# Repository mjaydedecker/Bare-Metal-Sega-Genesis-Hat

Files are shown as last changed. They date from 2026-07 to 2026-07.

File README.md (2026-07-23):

# Sega Genesis Controller HAT

A passive Raspberry Pi HAT exposing two DB9 (DE-9) ports for original Sega
Genesis / Mega Drive controllers, wired directly to the Pi's 40-pin GPIO
header.

<p align="center">
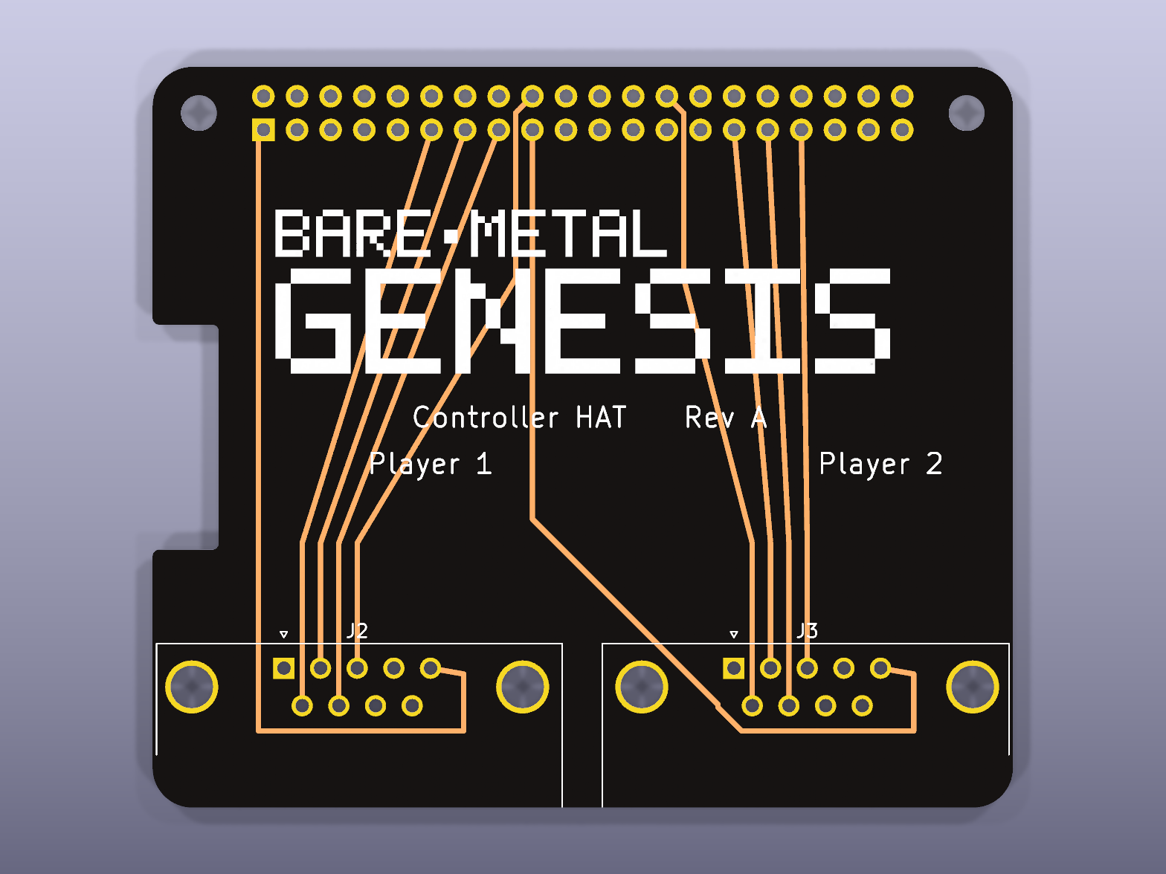
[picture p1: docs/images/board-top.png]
Board top render
  
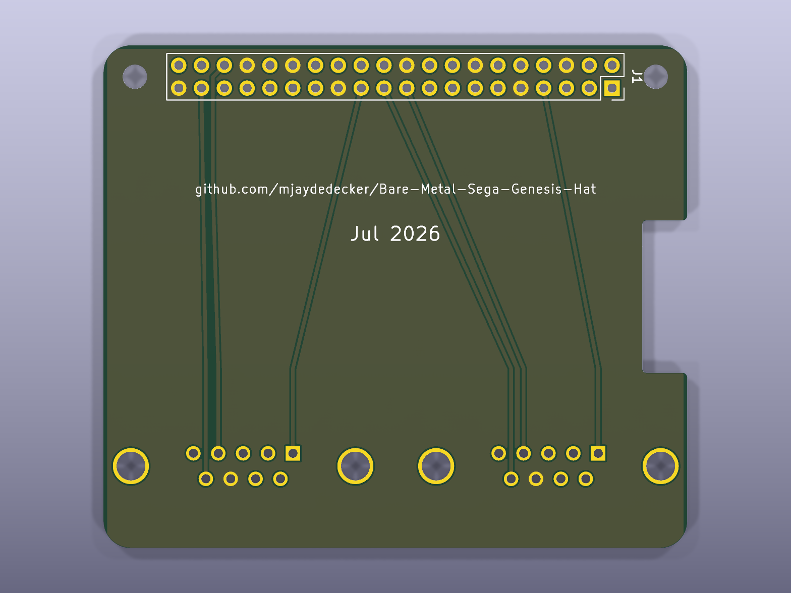
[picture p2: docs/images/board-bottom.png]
Board bottom render
  
</p>

Licensed under [CERN-OHL-S v2](LICENSE) — see [License](#license) below.

This board has no firmware of its own. The pin assignment and electrical
contract it implements are owned by the firmware repo,
[Bare-Metal-Sega-Genesis](../Bare-Metal-Sega-Genesis), specifically
`src/input/sega_board.h` and
`docs/superpowers/specs/2026-06-25-gpio-sega-controllers-design.md`. If
those ever disagree with this repo, the firmware repo wins — update this
board to match it, not the other way around.

See `docs/superpowers/specs/2026-07-21-controller-hat-v1-design.md` for the
full design rationale (why no ID EEPROM, no protection circuitry, no
stacking header) and `docs/superpowers/plans/2026-07-21-controller-hat-v1.md`
for how it was built.

A GitHub Actions workflow (`.github/workflows/verify-pinmap.yml`) checks on
every push that this board's schematic wiring matches the firmware repo's
`sega_board.h` exactly.

## Files

- `genesis-controller-hat.kicad_pro` / `.kicad_sch` / `.kicad_pcb` — the
  KiCad 10 project.
- `design_files/` — source design assets (currently the Bare-Metal Genesis
  logo handoff package); not needed to open or modify the board, kept for
  provenance.
- `scripts/` — the editing scripts used to build the schematic and PCB from
  KiCad's official `RaspberryPi-HAT` template. Not needed to open or modify
  the board in the KiCad GUI; kept for provenance/audit.

## Verifying the board

```bash
kicad-cli sch erc --severity-all genesis-controller-hat.kicad_sch
kicad-cli pcb drc --severity-all genesis-controller-hat.kicad_pcb
python3 scripts/check_pinmap.py ../Bare-Metal-Sega-Genesis/src/input/sega_board.h
```

`check_pinmap.py` (also run in CI on every push) confirms the schematic's
actual wiring matches the firmware repo's `sega_board.h`.

## License

Licensed under the [CERN Open Hardware Licence Version 2 - Strongly
Reciprocal (CERN-OHL-S v2)](LICENSE). Anyone may use, study, modify, and
distribute this design, including commercially — derivatives that are
distributed (as hardware or as design files) must be released under the
same license, with source design files made available. See the
[CERN-OHL-S FAQ](https://ohwr.org/project/cernohl/wikis/faq) for a plain-
language summary; the `LICENSE` file is the authoritative text.

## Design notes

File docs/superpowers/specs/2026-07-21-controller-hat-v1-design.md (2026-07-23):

# Sega Genesis Controller HAT v1 — Design

**Date:** 2026-07-21
**Status:** Design (approved, pending implementation plan)

## Goal

A passive Raspberry Pi add-on board ("HAT") that exposes two male DB9 (DE-9)
ports for original Sega Genesis / Mega Drive controllers (Genesis controller
cables end in a female DB9 connector, so the HAT needs male ports to mate
with them), wired directly to the Pi's 40-pin GPIO header per the electrical
contract and pin assignment already defined in the firmware repo
(`Bare-Metal-Sega-Genesis`, `src/input/sega_board.h` and
`docs/superpowers/specs/2026-06-25-gpio-sega-controllers-design.md`).

This project owns the physical board only. It has no firmware of its own — the
kernel repo is agnostic to this board via its `BoardPinMap` abstraction, so this
design's only job is to match that contract exactly.

## Scope decisions

- **Not officially HAT-spec certified.** No ID EEPROM (GPIO0/1 stay unpopulated
  and unconnected). This is a bare-metal kernel with no Linux/device-tree, so
  EEPROM auto-config has no consumer. GPIO0/1 are kept clear per the firmware
  doc's reservation, simply left unused rather than wired to an EEPROM.
- **Board outline:** Standard full-size HAT footprint, 65×56.5mm. Originally
  4 mounting holes matching the Pi 2/3/4B hole pattern (the firmware doc's
  `BoardPinMap` comment targets "Pi 2, 40-pin header, BCM numbering");
  **updated 2026-07-22:** the bottom two (`MH3`/`MH4`) were removed after
  the edge-mount DB9 connectors' brackets made them physically unusable —
  see "Components" below and the HAT repo's `README.md`. This board mounts
  on the remaining 2 top corner holes plus the GPIO header's friction fit,
  and no longer meets the official HAT spec's 4-hole requirement (already
  not pursuing certification, per above).
- **No electrical protection.** Data/SELECT lines wire straight from the DB9
  sockets to GPIO with no series resistors, no TVS/ESD diodes, no polyfuse on
  the 3.3V rail. This mirrors the firmware spec's documented contract exactly
  (it explicitly rules out level shifters, dividers, and shift registers, and
  relies on the Pi's internal `GPIOModeInputPullUp` pull-ups). Trade-off
  accepted: a shorted or miswired third-party DB9 cable could damage a GPIO pin
  — the same risk already accepted for the firmware team's bring-up jumper
  harness.
- **No stacking.** Plain 2×20 female GPIO header (J1), not a pass-through
  stacking header — nothing else is expected to stack on top of this HAT.
- **No extras.** No status LEDs, no use of the spare GPIO24-27 pins the
  firmware doc reserves for "future use." Bare minimum: 2 ports + header only.
- **EDA tool:** KiCad.

## Components

- **J1** — 2×20 female header, standard 0.1" pitch, plain (non-stacking),
  positioned to mate with the Pi's 40-pin GPIO header.
- **J2** — DB9 (DE-9) male pins, right-angle/edge-mount, Player 1.
- **J3** — DB9 (DE-9) male pins, right-angle/edge-mount, Player 2.
- J2 and J3 sit side-by-side along the board's bottom edge, opposite the GPIO
  header side, with their shells overhanging the board edge (9.12mm) so
  controller cables plug in horizontally at the board's edge, console-style.
  **Updated 2026-07-22:** switched from a vertical-mount footprint (opening
  faces straight up, cable plugs in from above) to this edge-mount one. The
  edge-mount connector's wider mounting bracket didn't fully clear the
  board's corner mounting holes at this board width, so the two affected
  holes (`MH3`/`MH4`) were removed — see the HAT repo's `README.md` "Known
  limitation: only 2 of the 4 official corner mounting holes remain".
  **Updated again 2026-07-22 (same day):** the connectors were corrected
  from female sockets (`DE9_Socket`) to male pins (`DE9_Pins`) — an original
  Genesis controller's cable ends in a female DB9, so the HAT needs male
  ports, not female, to receive it. This was never actually verified
  against a real controller or datasheet until physically checked; see the
  HAT repo's `docs/reviews/2026-07-22-pinmap-reassignment.md` for the full
  correction, including the GPIO pin reassignment it required (a male
  connector's pin order mirrors a female one's).
- No other active or passive components (no resistors, diodes, LEDs, EEPROM,
  or fuses).

## Pin map (authoritative source: firmware repo's `sega_board.h`)

**Updated 2026-07-22:** reassigned from the original table below (Port 1 =
GPIO4/5/6/7/8/9/10, Port 2 = GPIO11/12/13/16/17/22/23) to eliminate PCB
routing crossings — the original assignment interleaved each port's 7
signals across non-adjacent GPIO header columns. The new assignment groups
each port's signals onto physically adjacent header columns, nearest that
port's DB9 connector, which lets this board route both ports with zero
same-layer trace crossings. See `docs/reviews/2026-07-22-pinmap-reassignment.md`
for the full analysis.

BCM numbering, Pi 40-pin header:

| DB9 pin | Signal | Port 1 (J2) | Port 2 (J3) |
|---|---|---|---|
| 1 | Up | GPIO10 | GPIO26 |
| 2 | Down | GPIO23 | GPIO13 |
| 3 | Left | GPIO27 | GPIO6 |
| 4 | Right | GPIO17 | GPIO5 |
| 5 | +3.3V (NOT 5V) | Pi 3.3V rail| Pi 3.3V rail|
| 6 | TL (B / A) | GPIO24 | GPIO16 |
| 7 | SELECT (output) | GPIO22 | GPIO12 |
| 8 | GND | GND | GND |
| 9 | TR (C / Start) | GPIO4 | GPIO7 |

**Do not connect / leave unpopulated:**
- GPIO0/1 — reserved for HAT ID EEPROM by the firmware doc; unused here since
  there is no EEPROM on this board.
- GPIO2/3 — reserved for a deferred I2C-config DAC on the firmware side.
- GPIO14/15 — UART (Circle serial init).
- GPIO18-21 — I2S DAC (PCM_CLK/FS/DIN/DOUT), live `audio_output=i2s` option.
- GPIO8/9/11/25 — left spare by the firmware doc for possible future use
  (status LED, multitap); not populated in this v1 board.

If this table and `src/input/sega_board.h` in the firmware repo ever disagree,
the firmware repo's `BoardPinMap` is authoritative — this board must be updated
to match, not the other way around, since the kernel already ships against it.

## Deliverables

- KiCad project (schematic + PCB layout) checked into this repo.
- Silkscreen: "Player 1" / "Player 2" labels at J2/J3, pin-1 orientation marked
  on both DB9 footprints, board name/rev.
- A top-level README in this repo pointing at the firmware repo's pin-map
  source of truth, so the two can't silently drift.
- Not in this pass: fab-ready Gerbers/BOM/ordering. That's a follow-on step
  once the layout is reviewed.

## Testing / verification

No firmware logic exists in this project to unit test. Verification is:

1. **ERC/DRC clean in KiCad** — no unrouted nets, no footprint courtyard
   violations, silkscreen clear of the mounting holes and header.
2. **Continuity check** DB9 pin → GPIO pin against the table above once a
   board is fabricated, before first use with a real Pi.
3. **Functional bring-up** against the firmware repo's existing
   `docs/hardware-checklist-gpio-controllers.md` (checklist W) — that
   checklist already assumes "DB9 jacks wired to GPIO per `sega_board.h`
   (jumper harness or HAT)" and needs no changes for this board.

## Out of scope

- Official Raspberry Pi HAT certification / ID EEPROM.
- Any electrical protection circuitry (resistors, TVS, fuses).
- Stacking/pass-through header support for additional HATs.
- Status LEDs or use of the spare GPIO24-27 pins.
- Multitap or more than two controller ports (matches the firmware repo's
  explicit out-of-scope call for the same).
- Fabrication ordering (BOM sourcing, Gerber export, panelization).

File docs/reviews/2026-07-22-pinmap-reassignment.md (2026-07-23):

# GPIO Pin Reassignment for Zero-Crossing Routing

**Date:** 2026-07-22 (two separate reassignments, same day)
**Status:** Implemented (firmware repo + this HAT repo)

This document covers two reassignments done the same day: the first to fix
routing crossings (below), the second (see "Second reassignment" near the
bottom) to correct a wrong connector gender that had been designed against
without ever being checked.

## Background

The original GPIO pin assignment (Port 1 = GPIO4/5/6/7/8/9/10, Port 2 =
GPIO11/12/13/16/17/22/23, from the firmware repo's
`docs/superpowers/specs/2026-06-25-gpio-sega-controllers-design.md`) was
fixed before this HAT's PCB was laid out. Routing J2/J3 to that assignment
left `kicad-cli pcb drc` reporting 14 `tracks_crossing` violations (same-
layer shorts between different nets) that a scripted greedy two-layer router
could not eliminate, on top of a smaller set of pad-clearance issues.

## Root cause

`tracks_crossing` is not a routing-algorithm limitation — it's a consequence
of *which* GPIOs were assigned to which port. The Raspberry Pi's 40-pin
header has a fixed physical column order (BCM numbering does not follow
header position). Mapping the original assignment onto physical header
columns shows each port's 7 signals scattered across non-adjacent columns,
interleaved with the other port's signals and with reserved pins (I2S,
UART, I2C, EEPROM):

```
Port 1: GPIO4, 5, 6, 7, 8, 9, 10   -> interleaved with Port 2's columns
Port 2: GPIO11, 12, 13, 16, 17, 22, 23 -> interleaved with Port 1's columns
```

Since J2 (Port 1) and J3 (Port 2) sit at opposite ends of the board, and
each port's breakout tracks must reach across the header to their assigned
columns, an interleaved assignment forces Port 1's and Port 2's tracks to
physically cross each other en route — regardless of routing cleverness.

This was confirmed with a graph-theoretic analysis: model each net's
breakout path as a line segment from its connector pad to its target header
column, and build a conflict graph where two nets conflict if their segments
must cross. The original assignment's conflict graph was **not**
2-colorable across the two PCB layers (F.Cu/B.Cu) without at least 12-14
residual same-layer crossings — consistent with what DRC observed.

## Reassignment

The new assignment groups each port's 7 signals (1 SELECT + 6 data) onto
physically adjacent header columns, on the side of the header nearest that
port's own DB9 connector (Port 1 -> lower-numbered columns/nearer J2, Port 2
-> higher-numbered columns/nearer J3):

| Signal | DB9 pin | Port 1 (J2) | Port 2 (J3) |
|---|---|---|---|
| SELECT (output) | 7 | GPIO22 | GPIO12 |
| D0 -- Up | 1 | GPIO10 | GPIO26 |
| D1 -- Down | 2 | GPIO23 | GPIO13 |
| D2 -- Left | 3 | GPIO27 | GPIO6 |
| D3 -- Right | 4 | GPIO17 | GPIO5 |
| D4 -- TL (B / A) | 6 | GPIO24 | GPIO16 |
| D5 -- TR (C / Start)  | 9 | GPIO4 | GPIO7 |

Reservations (I2S GPIO18-21, UART GPIO14/15, I2C GPIO2/3, HAT EEPROM
GPIO0/1) are unchanged — only which *available* pins are used, and by which
port, changed. The available-but-unused set shifted from GPIO24-27 to
GPIO8/9/11/25.

Rebuilding the same conflict-graph analysis against this assignment found
exactly **one** crossing pair, and the resulting graph is fully
2-colorable — i.e. a 2-layer assignment exists with **zero** same-layer
crossings.

## Result

| DRC category | Before (old assignment) | After (new assignment) |
|---|:---:|:---:|
| `tracks_crossing` | 14  | **0** |
| `hole_clearance` | 4 | **0** |
| `shorting_items` | 2 | 6 |
| `copper_edge_clearance` | 2 | 2 |
| `silk_edge_clearance` | 5 | 5 |
| `solder_mask_bridge`  | 6 | 6 |
| `unconnected_items` | 2 | 2 |
| `lib_footprint_mismatch` | 1 | 1  |
| **Total errors/warnings** | 30 / 6 | **16 / 6** |

The reassignment achieved its goal: zero same-layer trace crossings and
zero hole-clearance violations. `shorting_items` rose from 2 to 6 — these
are cases where a diagonal breakout track, now free of other tracks, grazes
an unrelated J1 pad along its path. This is a smaller, more tractable
problem than the crossings it replaced: each is a single trace needing a
small manual jog in the KiCad GUI, not a fundamental routing conflict
requiring a different pin assignment or connector placement. All other
categories are unchanged, pre-existing conditions (see this repo's
`README.md` "Known limitation" sections for the itemized breakdown).

## Changes made (first reassignment)

- Firmware repo (`Bare-Metal-Sega-Genesis`): `src/input/sega_board.h`
  (`kBoardPinMap`), `test/test_sega_board.cpp` (updated assertions),
  `docs/superpowers/specs/2026-06-25-gpio-sega-controllers-design.md` (pin
  table + reservations list).
- This repo: `genesis-controller-hat.kicad_sch` (J2/J3 rewired),
  `genesis-controller-hat.kicad_pcb` (J2/J3 re-placed and re-routed, ground
  plane re-filled), `docs/superpowers/specs/2026-07-21-controller-hat-v1-design.md`,
  `README.md`.
- `.github/workflows/verify-pinmap.yml` + `scripts/check_pinmap.py` (added
  separately) now catch any future drift between the two repos' pin maps
  automatically, on every push.

## Second reassignment: connector gender correction

Later the same day, J2/J3 were found to be **female** DB9 sockets when a
real Sega Genesis controller's cable ends in a **female** DB9 connector —
the HAT needs **male** ports, the opposite of what had been built. This was
never checked against a datasheet, photo, or real hardware at any point
before this; it was caught only by physically inspecting two real
controllers (original and third-party) after being asked directly whether
the connector gender was correct.

### Why the first reassignment stopped working

A male DB9's physical pin order is the mirror image of a female one's,
left-to-right (pin 1 stays put; every other pin reflects to the opposite
side). The reassignment above was matched to the *female* pin order:

```
Female J2/J3 physical order (left to right): +3.3V, D5, D2, GND, SELECT, D1, D4, D0
Male J2/J3 physical order (left to right):   D0, D4, D1, SELECT, GND, D2, D5, +3.3V
```

Swapping the footprint without re-deriving the assignment produced a
conflict graph with **65 edges that was not 2-colorable** (verified by
building the actual conflict graph and attempting a bipartite coloring,
not just inspecting it by eye) — the breakout order and target order were
now almost fully reversed, the worst case for same-layer routing.

### New assignment

Re-derived the same way as the first reassignment, but matched to the
male connector's actual left-to-right pin order (`D0, D4, D1, SELECT, D2,
D3, D5`), using the lowest 7 available GPIO columns for Port 1 and the
highest 7 for Port 2, each assigned in that same order so breakout order
and target order stay monotonic:

| Signal | DB9 pin | Port 1 (J2) | Port 2 (J3) |
|---|---|---|---|
| SELECT (output) | 7 | GPIO22 | GPIO6 |
| D0 -- Up | 1 | GPIO4 | GPIO11 |
| D1 -- Down | 2 | GPIO27 | GPIO5 |
| D2 -- Left | 3 | GPIO24 | GPIO13 |
| D3 -- Right | 4 | GPIO10 | GPIO16 |
| D4 -- TL (B / A) | 6 | GPIO17 | GPIO7 |
| D5 -- TR (C / Start)  | 9 | GPIO9 | GPIO26 |

GPIO12/23 (used by the first reassignment) move to spare; GPIO9/11
(previously spare) are now used. Reservations are unchanged.

A pure-diagonal, single-layer crossing check against this assignment
(same technique as the first reassignment's validation) found **zero**
crossings — confirmed computationally before implementing, not assumed
from the monotonic-order argument alone.

### Result

| DRC category | Before 2nd reassignment (male footprint, old GPIO map) | After 2nd reassignment |
|---|:---:|:---:|
| `tracks_crossing` (simple diagonal, pre-jog) | 26 | 0 |
| `tracks_crossing` (final, with row-A jogs + `+3V3`/`GND` routing) | n/a | 4 |
| `shorting_items` | 2 | 0 |
| `solder_mask_bridge` | 1 | 0 |
| `copper_sliver` | 1 | 0 |
| **Total DRC errors/warnings** | n/a | **4 / 0** |

The 4 residual `tracks_crossing` all involve `+3V3`: DB9 pin 5 sits at the
far end of each connector's mirrored pin order from the header's own
+3.3V pins (J1 pins 1 and 17), so its trace necessarily sweeps across most
of the header. Building the conflict graph confirmed `+3V3` and `GND`
conflict with nearly every other net (15 and 9 conflicts respectively out
of 16 possible) — not 2-colorable, a genuine topological limit of 2-layer
routing for this specific connector's pin order, not a missed layer
assignment. Swapping which of J1's two +3.3V pins each port uses doesn't
help: J3 is far from both (26.3mm to the nearer one, 46.6mm to the other),
so its `+3V3` diagonal is long either way.

### Changes made (second reassignment)

- Firmware repo: `src/input/sega_board.h`, `test/test_sega_board.cpp`,
  `docs/superpowers/specs/2026-06-25-gpio-sega-controllers-design.md`
  (same files as the first reassignment, updated again).
- This repo: schematic symbols swapped `Connector:DE9_Socket_MountingHoles`
  → `Connector:DE9_Pins_MountingHoles` on J2/J3 (with all labels mirrored
  to match the new pin geometry, and J1's own GPIO9/GPIO11 wiring
  activated / GPIO12/GPIO23 wiring freed to match); PCB footprints swapped
  `DSUB-9_Socket_Horizontal_...` → `DSUB-9_Pins_Horizontal_...` on J2/J3
  (re-placed since the mounting holes also mirror position, fully
  re-routed); `scripts/check_pinmap.py` updated for the mirrored pin
  offsets; `README.md`, this doc, and the design spec updated.

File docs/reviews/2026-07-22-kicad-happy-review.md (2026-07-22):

# KiCad Design Review — Sega Genesis Controller HAT

**Date:** 2026-07-22
**Tool:** kicad-happy v2.1.0 (`kicad`, `emc` skills)
**Analysis run:** `analysis/2026-07-22_0915/`
**Files reviewed:** `genesis-controller-hat.kicad_sch`, `genesis-controller-hat.kicad_pcb`

## Verdict

**No blockers.** This is a 3-component passive board (one generic 2×20 GPIO
header, two DB9 sockets) with no ICs, no regulators, and no analog
subcircuits — most of this tool's IC-datasheet and SPICE-verification
machinery doesn't apply here. Of the findings that *do* apply, two are
real, pre-existing, already-documented items (the stale PCB net table, the
missing ground plane) and several others are false positives caused by this
design repurposing Pi GPIO pins whose net names still carry the Raspberry
Pi's generic alternate-function labels (`GPCLK0`, `SPI0.SCLK`, etc.) even
though this board drives them as plain digital I/O, not as a hardware clock
or SPI bus.

## Analyses Run

| Analysis | Run? | Result |
|---|---|---|
| Datasheet sync | No | 0/2 unique parts have MPNs (generic DB9/header footprints, no distributor part chosen yet) — see Verification Basis below |
| `analyze_schematic.py` | Yes | 0 electrical findings beyond sourcing/lifecycle disclosure |
| `analyze_pcb.py --full` | Yes | 20 findings (placement, routing, EMC-adjacent) |
| `cross_analysis.py` | Yes | 8 findings (all EMC-plane-related, overlaps with EMC run) |
| `analyze_emc.py` | Yes | included in the 20/8 above |
| SPICE | **Not run** | no `ngspice`/`ltspice`/`xyce` on this machine, and this board has no simulatable subcircuit (no filters, dividers, or op-amps — just direct pass-through wiring) |
| `analyze_thermal.py` | Yes | 0 findings, thermal score `SKIPPED` — no power-dissipating components on this board |
| `analyze_gerbers.py` | **Not run** | no gerbers generated yet; fabrication output was explicitly out of scope for this v1 (see the project's own design spec) |
| Lifecycle audit | **Not run** | no MPNs assigned yet, nothing to look up |
| Prior review delta | N/A | this is the first review of this project |

## Verification Basis

`DS-001` fired (no datasheets, 0/2 parts have MPNs). Per this skill's own
disclosure rule: **every claim below is a consistency check, not a
datasheet-verified one.** That said, this project's own build process
already did the equivalent of datasheet verification for the parts that
matter here — not against a manufacturer PDF, but against the two sources
that actually govern this design:

- **Pin mapping** — every net was verified against the firmware repo's
  `src/input/sega_board.h` (the authoritative pin-map contract this whole
  board is built to implement), independently confirmed three times during
  this project's own build/review process (once per DB9 connector, plus the
  final whole-branch review), each time by re-deriving the schematic
  label → PCB pad net → target GPIO pad chain and comparing it against that
  table pin-by-pin.
- **Footprint correctness** — the 2×20 header and both DE9 socket footprints
  are KiCad's own official library parts (`Connector_PinSocket_2.54mm`,
  `Connector_Dsub`), not hand-drawn, so there's no custom pin-to-pad mapping
  to get wrong the way a community-authored symbol could.

So while `DS-001`'s literal trigger condition is true, this isn't a case of
"nobody checked the pinout" — it's a case of "the pinout was checked against
a domain-specific spec instead of a component datasheet," which is the
correct source of truth for a board whose entire purpose is implementing
someone else's protocol on someone else's GPIO header.

## Findings

### High/Error

**GP-002 — No ground plane zones detected.** Real, not a false positive.
Confirmed directly: the PCB has exactly one `zone` object, and it's an
unfilled keepout zone left over from the official `RaspberryPi-HAT` template
(named `"PoE"`, net-less, on `B.Cu` — irrelevant to a DB9-only board, same
class of template leftover already cleaned up elsewhere in this project's
final review pass, just missed for this one zone object specifically). There
is genuinely no ground or +3.3V copper pour anywhere on this board — every
net was routed as individual point-to-point traces in Task 6's greedy
router. For this board's actual signal profile (a handful of GPIO lines
polled at frame rate, no RF, no high-speed buses), a ground plane isn't
electrically required for function, but it's cheap insurance for noise
immunity and it's what a "real" 2-layer board would normally have. **Recommend
adding a ground pour on B.Cu in the same manual GUI cleanup pass the project
already has scheduled for the routing crossings** (see the project's
`README.md` "Known limitation" section) — and deleting the leftover `"PoE"`
keepout zone while in there.

**RT-001 — Unrouted net +5V (2 pads).** Already known and already documented.
This is the same stale-net-table situation the project's own `README.md`
calls out explicitly ("PCB net table includes stale entries") — the +5V net
is a leftover from the vanilla template (this design never uses 5V, only
3.3V, per the approved design spec), and J1's two physical +5V pins were
deliberately never wired to anything. Not a new finding, not an action item
beyond what's already documented.

**PM-002 — "J1 is 0.43mm from board edge."** Likely a tool false positive
for this specific footprint, not a real manufacturability defect. Compare
against the tool's own treatment of J2/J3/MH2/MH4, all of which it correctly
recognized as "edge-mount footprint — by-design at board edge" and
downgraded to `info`. J1 didn't get that same recognition, but it's under
the identical constraint: a HAT's 40-pin GPIO header position is fixed by
the official Raspberry Pi HAT mechanical spec (it must align with the Pi's
own header), not a placement choice this project made — and J1's position
was never touched in this project, inherited verbatim from KiCad's own
official `RaspberryPi-HAT` template. **No action recommended**; flagging
this as a tool limitation (its "is this footprint supposed to be at the
edge" heuristic doesn't recognize a generic 2×20 socket the way it
recognizes the DB9 footprints) rather than a design defect.

**SS-001 — Sourcing blocker: BOM has <50% MPN coverage (0/2 unique parts).**
Real, expected, not yet in scope. This project's own design spec explicitly
deferred "fab-ready Gerbers/BOM/ordering" to a follow-on step past this v1.
Genuine pre-order todo (pick specific DB9 socket and header part numbers,
verify footprint match), not a v1 defect.

**RP-002 (2 of 6 flagged `error`) — "clock net /GPIO4/GPCLK0 crosses +3V3
plane gap"; "clock net /GPIO11/SPI0.SCLK crosses GND plane gap."** False
positive from net-name pattern matching, not a real EMC clock-routing issue.
`GPIO4`/`GPIO11` are this design's two DB9 **SELECT** lines (per
`sega_board.h`) — plain, software-toggled digital outputs, not hardware
clock generators. Their net names still carry the Raspberry Pi's *generic*
alternate-function label (`GPCLK0`/`SPI0.SCLK` — every Pi GPIO pin has one,
inherited straight from the official KiCad template's own per-pin labels)
even though this application never uses that alternate function. The EMC
analyzer's clock-detection heuristic pattern-matches on the `GPCLK`/`SCLK`
substring in the net name without knowing this. **No action needed** — but
worth being aware of if this finding resurfaces in a future automated run,
since the underlying net names won't change (they're inherited from the
Pi's own GPIO naming convention, not something this project controls).

### Warning

**RP-002 (4 of 6, `warning`) — "spi net /GPIO{7,8,9,10}/SPI0.* crosses +3V3
plane gap."** Same root cause and same verdict as the two `error`-level
instances above — these four GPIO pins are this design's TL/TR (button)
lines on both DB9 ports, not a real SPI bus. False positive, no action.

**IO-001 (high, listed as 2 findings) — "No EMC filtering near J1/J3."**
Expected and already a documented, approved design decision, not a gap this
review is surfacing for the first time: the project's design spec explicitly
calls for **no protection components** (no series resistors, no TVS/ESD
diodes) — direct wiring only, matching the firmware repo's own electrical
contract, which was deliberately chosen over filtering during this project's
brainstorming phase. Consistent with the design intent, not a defect.

**CK-003 (2) — "Clock ... routed near connector."** Same false-positive
root cause as the RP-002 clock findings above (net-name pattern match on
`GPCLK0`/`SCLK`, not an actual clock signal). No action.

**TE-001 — Test point coverage: 0/28 nets (0%).** Expected for a low-volume
hobbyist board with no ICT/production-test requirement. Not a defect for
this project's scope.

**VS-001 — "Via stitching may be insufficient."** Consequence of GP-002 (no
ground plane exists yet to stitch). Resolves itself once a ground pour is
added; not a separate action item.

### Info (no action needed — confirmed correct-by-design)

- **PM-002** (J2/J3/MH2/MH4 edge distances) — all four correctly recognized
  by the tool itself as intentional edge-mount/HAT-mounting-hole geometry.
- **EP-AUD** (ESD audit: none coverage on J1/J2/J3) — matches the approved
  "no protection components" design decision.
- **IO-002** / **CG-AUD** (J2/J3: only 1 ground pin out of 9, 8:1
  signal-to-ground ratio) — inherent to the DB9 Sega Genesis controller
  connector standard itself (pin 8 is the only ground on the real
  connector); not something a HAT redesign could change without breaking
  compatibility with real controllers.
- **PS-002** (+3V3/GND "plane split" into 2/8 islands) — another view of the
  same stale-net-table / no-ground-plane situation as GP-002/RT-001 above,
  not a new issue.
- **EE-001** (board cavity resonance estimate), **GP-001** (return path data
  unavailable — no plane to analyze), **SU-001** (F.Cu/B.Cu both carry
  signals) — informational only, no action implied.

## Known Analyzer Limitations for This Board

- SPICE and thermal analysis exist in the toolchain but have nothing to
  simulate/model here — this board has zero analog subcircuits and zero
  power-dissipating components. Their "0 findings" results are a correct
  reflection of the design, not a gap.
- Gerbers and a lifecycle audit weren't run because neither fabrication
  outputs nor MPNs exist yet — both are legitimate next steps before
  ordering, not part of this v1's stated scope.
- Net-name-driven heuristics (clock/SPI detection) don't have visibility
  into *actual* pin usage for a design that deliberately repurposes a
  general-purpose header's alternate-function-named pins as plain GPIO —
  worth remembering if this board is re-analyzed later and the same
  `GPCLK0`/`SPI0.*` findings reappear.

## Recommended Follow-ups (fold into the existing pre-fab GUI cleanup pass)

The project's `README.md` already documents a manual KiCad-GUI cleanup pass
for the routing crossings/shorts and the clipped "Player 2" label. Add two
items to that same list:

1. Pour a ground plane (B.Cu is the natural choice, since most signal
   routing is on F.Cu) and stitch it to J1's GND pins.
2. Delete the leftover unfilled `"PoE"` keepout zone (a separate object from
   the `"PoE"` text label already removed in this project's final review).

Neither blocks the board's electrical function as designed; both are cheap
to do in the same GUI session already planned for the routing cleanup.

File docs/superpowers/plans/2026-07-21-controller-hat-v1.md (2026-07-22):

# Sega Genesis Controller HAT v1 Implementation Plan

> **For agentic workers:** REQUIRED SUB-SKILL: Use superpowers:subagent-driven-development (recommended) or superpowers:executing-plans to implement this plan task-by-task. Steps use checkbox (`- [ ]`) syntax for tracking.

**Goal:** Produce a KiCad 9 schematic + PCB for a passive Raspberry Pi HAT carrying two DB9 Sega Genesis controller ports, wired to the Pi's 40-pin GPIO header exactly per `src/input/sega_board.h` in the firmware repo, starting from KiCad's own official `RaspberryPi-HAT` template so the mechanical spec (65×56.5mm outline, mounting holes, GPIO header position) is correct by construction rather than hand-derived.

**Architecture:** Copy KiCad's bundled `RaspberryPi-HAT` template (already mechanically correct per the Raspberry Pi Foundation's `hat-board-mechanical.pdf`), strip the parts of it we don't want (ID EEPROM circuit, 5V), then add two `DE9_Socket_MountingHoles` connectors and wire them to the header using KiCad's existing per-pin net labels. All schematic edits are done with a small, tested S-expression parser/serializer script (not hand-edited text) because KiCad's file format is whitespace-sensitive enough that naive string edits can silently corrupt the file — verified empirically during design (a naive text-splice edit produced a file that segfaulted `kicad-cli`). Every task ends with a `kicad-cli sch erc` or `kicad-cli pcb drc` run against a known-good violation count.

**Tech Stack:** KiCad 9.0.8 (`kicad-cli` for ERC/DRC/SVG export), Python 3. Schematic edits go through a custom S-expression parser (`scripts/kicad_sexpr.py`) since no equivalent scripting module for `eeschema` is available. PCB edits go through the real `pcbnew` Python module (`/usr/lib/python3/dist-packages/pcbnew.py`, installed alongside the `kicad` apt package) — confirmed working during planning, and preferred over hand-written S-expressions for the PCB because it manages the net table for you instead of requiring manual net-code bookkeeping.

## Global Constraints

- Electrical contract is fixed by `docs/superpowers/specs/2026-07-21-controller-hat-v1-design.md` in this repo: DB9 pin 5 = +3.3V (not 5V), pin 8 = GND, data/SELECT direct to GPIO, no protection components, no ID EEPROM, no stacking header, no LEDs.
- Pin map is fixed by the firmware repo's `src/input/sega_board.h` (BCM numbering) — this plan is not the source of truth for pin choices, it only implements the already-approved table.
- Every schematic-editing task must leave `kicad-cli sch erc` reporting the exact violation count stated in that task (not "fewer" or "roughly") — the counts were measured empirically against the real template during planning and are exact targets, not estimates.
- All schematic edits (Tasks 2-5) go through `scripts/kicad_sexpr.py`, never hand-typed raw S-expression text pasted into `.kicad_sch` directly. PCB edits (Task 6) go through the real `pcbnew` Python module instead — discovered mid-planning to be installed and working in this environment, and preferred for the PCB specifically because it manages net-table bookkeeping for you rather than requiring it be replicated by hand. Neither task hand-edits file text directly.

---

## Reference data (used by every task below)

**Raspberry Pi 40-pin header (BCM numbering) — physical pin ↔ GPIO, confirmed against the label text already embedded in KiCad's own `RaspberryPi-HAT` template schematic:**

| Physical pin | GPIO | Template label text (verbatim, `{slash}` is KiCad's literal escape for `/`) |
|---|---|---|
| 7  | GPIO4  | `GPIO4{slash}GPCLK0` |
| 29 | GPIO5  | `GPIO5` |
| 31 | GPIO6  | `GPIO6` |
| 26 | GPIO7  | `GPIO7{slash}SPI0.CE1` |
| 24 | GPIO8  | `GPIO8{slash}SPI0.CE0` |
| 21 | GPIO9  | `GPIO9{slash}SPI0.MISO` |
| 19 | GPIO10 | `GPIO10{slash}SPI0.MOSI` |
| 23 | GPIO11 | `GPIO11{slash}SPI0.SCLK` |
| 32 | GPIO12 | `GPIO12{slash}PWM0` |
| 33 | GPIO13 | `GPIO13{slash}PWM1` |
| 36 | GPIO16 | `GPIO16` |
| 11 | GPIO17 | `GPIO17` |
| 15 | GPIO22 | `GPIO22` |
| 16 | GPIO23 | `GPIO23` |

**Unused GPIO pins to strip (their template labels get deleted, not wired):** GPIO2, GPIO3, GPIO14, GPIO15, GPIO18, GPIO19, GPIO20, GPIO21, GPIO24, GPIO25, GPIO26, GPIO27 (physical pins 3, 5, 8, 10, 12, 35, 38, 40, 18, 22, 37, 13). GPIO0/GPIO1 (physical pins 27/28) connect to the ID EEPROM sub-circuit via two same-name local-label pairs, `ID_SDA` and `ID_SCL` (confirmed by inspection — not "wired directly" as first assumed during planning; see Task 2's correction note), removed in Task 2 along with the EEPROM circuit itself.

**Genesis DB9 pinout (from `src/input/sega_board.h` / the approved HAT spec):**

| DB9 pin | Signal | Port 1 (J2) → GPIO | Port 2 (J3) → GPIO |
|---|---|---|---|
| 1 | Up | GPIO5 | GPIO12 |
| 2 | Down | GPIO6 | GPIO13 |
| 3 | Left | GPIO7 | GPIO16 |
| 4 | Right | GPIO8 | GPIO17 |
| 5 | +3.3V | local +3.3V symbol | local +3.3V symbol |
| 6 | TL (B/A) | GPIO9 | GPIO22 |
| 7 | SELECT | GPIO4 | GPIO11 |
| 8 | GND | local GND symbol | local GND symbol |
| 9 | TR (C/Start) | GPIO10 | GPIO23 |
| 0 (shell/mounting pad) | — | no-connect | no-connect |

**KiCad library identifiers confirmed present on this system (`kicad-cli version` → 9.0.8):**
- GPIO header (already placed correctly by the template): `Connector_Generic:Conn_02x20_Odd_Even`, footprint `Connector_PinSocket_2.54mm:PinSocket_2x20_P2.54mm_Vertical`.
- DB9 socket: symbol `Connector:DE9_Socket_MountingHoles`, footprint `Connector_Dsub:DSUB-9_Socket_Vertical_P2.77x2.84mm_MountingHoles`. Symbol pins 1–9 map straight to DB9 pins 1–9; pin `"0"` is the shell/mounting-hole pad.
- Power flags: `power:+3.3V`, `power:GND`, `power:PWR_FLAG` (the last has a `power_out` pin and is how you tell ERC "this net is driven from outside the sheet" — required because `power:+3.3V`/`power:GND` symbols themselves have `power_in` pins, not `power_out`).

**Empirically measured baseline** (untouched copy of `/usr/share/kicad/template/RaspberryPi-HAT`, after fixing this machine's KiCad library tables — see Task 0):
- `kicad-cli sch erc`: **31 violations = 29 errors + 2 warnings.**
  - 26 errors: `label_dangling` (one per unused/unwired GPIO label — 14 of these are pins we'll wire, 12 are pins we'll delete).
  - 3 errors: `power_pin_not_driven` (`#PWR04` = +3.3V, `#PWR01` = +5V, `#PWR02` = one of the two GND flags).
  - 2 warnings: `lib_symbol_mismatch` on `R1`/`R2` (`R_Small` footprint fields differ from the library copy — cosmetic, disappears once those parts are deleted in Task 2).
- `kicad-cli pcb drc`: 1 warning (`lib_footprint_mismatch` on J1, cosmetic/pre-existing) + 9 unconnected-pad errors (GPIO header's GND/+3.3V/+5V pins aren't copper-tied together yet — expected, nothing is routed in a blank template).

---

### Task 0: Fix this machine's KiCad library tables (one-time, environment-only — not a repo change)

KiCad was just installed via apt and has never been run interactively, so its global `sym-lib-table` doesn't exist yet (only a partial `fp-lib-table` gets auto-created the first time `kicad-cli` touches a project). Without this, `kicad-cli sch erc` reports spurious `lib_symbol_issues` warnings for every standard library (`power`, `Device`, `Connector_Generic`, ...) because it can't resolve them, and edits that add new library symbols (the `PWR_FLAG` fix in Task 2) will fail to resolve at all.

**Files:** none in the repo — this only touches `~/.config/kicad/9.0/`.

- [ ] **Step 1: Copy KiCad's default global symbol table into place**

```bash
mkdir -p ~/.config/kicad/9.0
cp /usr/share/kicad/template/sym-lib-table ~/.config/kicad/9.0/sym-lib-table
```

- [ ] **Step 2: Verify the fp-lib-table already exists and is the full default (not an empty stub)**

```bash
wc -l ~/.config/kicad/9.0/fp-lib-table
```

Expected: **157** (matches `/usr/share/kicad/template/fp-lib-table` line count). If it's much shorter (e.g. 1-2 lines), copy the template version the same way as Step 1, substituting `fp-lib-table` for `sym-lib-table`.

- [ ] **Step 3: Confirm the fix with a scratch copy of the vanilla template**

```bash
rm -rf /tmp/hat-baseline-check && cp -r /usr/share/kicad/template/RaspberryPi-HAT /tmp/hat-baseline-check
cd /tmp/hat-baseline-check
kicad-cli sch erc --severity-all RaspberryPi-HAT.kicad_sch
grep -c "; error" RaspberryPi-HAT-erc.rpt
grep -c "; warning" RaspberryPi-HAT-erc.rpt
```

Expected: `29` errors, `2` warnings (matches the baseline table above — if you see extra `lib_symbol_issues` warnings, the library table isn't picked up yet; double check the path is exactly `~/.config/kicad/9.0/` and matches the version `kicad-cli version` reports).

- [ ] **Step 4: Clean up the scratch copy**

```bash
rm -rf /tmp/hat-baseline-check
```

No commit for this task — it's a local machine fix, not a repo change.

---

### Task 1: Scaffold the project from KiCad's official HAT template

**Files:**
- Create: `genesis-controller-hat.kicad_pro`
- Create: `genesis-controller-hat.kicad_sch`
- Create: `genesis-controller-hat.kicad_pcb`
- Create: `scripts/kicad_sexpr.py`

**Interfaces:**
- Produces: `scripts/kicad_sexpr.py` exposes `parse(text) -> tree`, `dumps(tree) -> text`, `find_symbols_by_ref(tree, refs: set[str]) -> list[list]`, `get_property(symbol_node, name) -> str|None`, `remove_symbols_by_ref(tree, refs: set[str]) -> int` (returns count removed), `remove_labels_by_text(tree, texts: set[str]) -> int`, `root_uuid(tree) -> str`, `make_power_symbol(lib_id, ref, value, at_xy, project, root_uuid_str) -> list`, `make_db9_symbol(ref, value, at_xy, project, root_uuid_str) -> list`, `make_label(text, at_xy, angle=180) -> list`, `make_no_connect(at_xy) -> list`. Every later schematic task imports this module.

- [ ] **Step 1: Copy the template into the repo under a new name**

```bash
cp /usr/share/kicad/template/RaspberryPi-HAT/RaspberryPi-HAT.kicad_pro genesis-controller-hat.kicad_pro
cp /usr/share/kicad/template/RaspberryPi-HAT/RaspberryPi-HAT.kicad_sch genesis-controller-hat.kicad_sch
cp /usr/share/kicad/template/RaspberryPi-HAT/RaspberryPi-HAT.kicad_pcb genesis-controller-hat.kicad_pcb
```

- [ ] **Step 2: Write the S-expression helper module**

Create `scripts/kicad_sexpr.py`:

```python
"""Round-trip-safe S-expression parser/serializer for KiCad 9 files, plus
helpers for the specific find/remove/create operations this project's
schematic-editing scripts need. Not a general KiCad API replacement — no
pcbnew module is installed in this environment, so file-format editing is
the only scripting path available."""

import uuid as _uuid

class Sym(str):
    """A bare (unquoted) token, as opposed to a quoted string."""
    pass

def parse(text):
    pos = 0
    n = len(text)

    def skip_ws(p):
        while p < n and text[p] in " \t\r\n":
            p += 1
        return p

    def parse_atom(p):
        if text[p] == '"':
            p += 1
            buf = []
            while text[p] != '"':
                if text[p] == '\\':
                    buf.append(text[p:p + 2])
                    p += 2
                else:
                    buf.append(text[p])
                    p += 1
            return "".join(buf), p + 1
        start = p
        while p < n and text[p] not in " \t\r\n()":
            p += 1
        return Sym(text[start:p]), p

    def parse_expr(p):
        p = skip_ws(p)
        assert text[p] == '(', f"expected '(' at {p}"
        p += 1
        items = []
        while True:
            p = skip_ws(p)
            if text[p] == ')':
                return items, p + 1
            if text[p] == '(':
                sub, p = parse_expr(p)
                items.append(sub)
            else:
                atom, p = parse_atom(p)
                items.append(atom)

    tree, _ = parse_expr(skip_ws(0))
    return tree

def serialize(node):
    if isinstance(node, Sym):
        return str(node)
    if isinstance(node, str):
        return '"' + node.replace('\\', '\\\\').replace('"', '\\"') + '"'
    return "(" + " ".join(serialize(c) for c in node) + ")"

def dumps(tree):
    return serialize(tree)

def get_tag(node):
    return node[0] if isinstance(node, list) and node else None

def get_property(symbol_node, name):
    for child in symbol_node:
        if isinstance(child, list) and get_tag(child) == "property" and child[1] == name:
            return child[2]
    return None

def find_symbols_by_ref(tree, refs):
    return [n for n in tree if isinstance(n, list) and get_tag(n) == "symbol"
            and get_property(n, "Reference") in refs]

def remove_symbols_by_ref(tree, refs):
    before = len(tree)
    tree[:] = [n for n in tree if not (isinstance(n, list) and get_tag(n) == "symbol"
                                        and get_property(n, "Reference") in refs)]
    return before - len(tree)

def remove_labels_by_text(tree, texts):
    before = len(tree)
    tree[:] = [n for n in tree if not (isinstance(n, list) and get_tag(n) == "label"
                                        and n[1] in texts)]
    return before - len(tree)

def root_uuid(tree):
    for node in tree:
        if isinstance(node, list) and get_tag(node) == "uuid":
            return node[1]
    raise ValueError("no top-level uuid found")

def project_name(tree):
    for node in tree:
        if isinstance(node, list) and get_tag(node) == "symbol":
            for child in node:
                if isinstance(child, list) and get_tag(child) == "instances":
                    for proj in child[1:]:
                        return proj[1]
    raise ValueError("no instances/project block found to infer project name")

def _effects(size=1.27):
    return [Sym("effects"), [Sym("font"), [Sym("size"), str(size), str(size)]]]

def make_power_symbol(lib_id, ref, value, at_xy, project, root_uuid_str):
    x, y = at_xy
    new_uuid = str(_uuid.uuid4())
    return [
        Sym("symbol"),
        [Sym("lib_id"), lib_id],
        [Sym("at"), str(x), str(y), "0"],
        [Sym("unit"), "1"],
        [Sym("exclude_from_sim"), Sym("no")],
        [Sym("in_bom"), Sym("yes")],
        [Sym("on_board"), Sym("yes")],
        [Sym("dnp"), Sym("no")],
        [Sym("uuid"), new_uuid],
        [Sym("property"), "Reference", ref, [Sym("at"), str(x), str(y + 3.81), "0"],
         [Sym("effects"), [Sym("font"), [Sym("size"), "1.27", "1.27"]], [Sym("hide"), Sym("yes")]]],
        [Sym("property"), "Value", value, [Sym("at"), str(x), str(y - 4.32), "0"], _effects()],
        [Sym("property"), "Footprint", "", [Sym("at"), str(x), str(y), "0"], _effects()],
        [Sym("property"), "Datasheet", "", [Sym("at"), str(x), str(y), "0"], _effects()],
        [Sym("pin"), "1", [Sym("uuid"), str(_uuid.uuid4())]],
        [Sym("instances"), [Sym("project"), project,
                             [Sym("path"), "/" + root_uuid_str,
                              [Sym("reference"), ref], [Sym("unit"), "1"]]]],
    ]

def make_db9_symbol(ref, value, at_xy, project, root_uuid_str):
    x, y = at_xy
    new_uuid = str(_uuid.uuid4())
    return [
        Sym("symbol"),
        [Sym("lib_id"), "Connector:DE9_Socket_MountingHoles"],
        [Sym("at"), str(x), str(y), "0"],
        [Sym("unit"), "1"],
        [Sym("exclude_from_sim"), Sym("no")],
        [Sym("in_bom"), Sym("yes")],
        [Sym("on_board"), Sym("yes")],
        [Sym("dnp"), Sym("no")],
        [Sym("uuid"), new_uuid],
        [Sym("property"), "Reference", ref, [Sym("at"), str(x), str(y - 17.78), "0"], _effects()],
        [Sym("property"), "Value", value, [Sym("at"), str(x), str(y - 15.875), "0"], _effects()],
        [Sym("property"), "Footprint",
         "Connector_Dsub:DSUB-9_Socket_Vertical_P2.77x2.84mm_MountingHoles",
         [Sym("at"), str(x), str(y), "0"], [Sym("effects"), [Sym("font"), [Sym("size"), "1.27", "1.27"]], [Sym("hide"), Sym("yes")]]],
        [Sym("property"), "Datasheet", "~", [Sym("at"), str(x), str(y), "0"],
         [Sym("effects"), [Sym("font"), [Sym("size"), "1.27", "1.27"]], [Sym("hide"), Sym("yes")]]],
        [Sym("instances"), [Sym("project"), project,
                             [Sym("path"), "/" + root_uuid_str,
                              [Sym("reference"), ref], [Sym("unit"), "1"]]]],
    ]

def make_label(text, at_xy, angle=180):
    x, y = at_xy
    return [Sym("label"), text, [Sym("at"), str(x), str(y), str(angle)],
            [Sym("effects"), [Sym("font"), [Sym("size"), "1.27", "1.27"]],
             [Sym("justify"), Sym("left"), Sym("bottom")]],
            [Sym("uuid"), str(_uuid.uuid4())]]

def make_no_connect(at_xy):
    x, y = at_xy
    return [Sym("no_connect"), [Sym("at"), str(x), str(y)], [Sym("uuid"), str(_uuid.uuid4())]]
```

- [ ] **Step 3: Verify the module parses and round-trips the copied schematic without corruption**

```bash
python3 -c "
import sys; sys.path.insert(0, 'scripts')
import kicad_sexpr as ks
tree = ks.parse(open('genesis-controller-hat.kicad_sch').read())
open('/tmp/roundtrip-check.kicad_sch', 'w').write(ks.dumps(tree))
print('top-level items:', len(tree))
"
kicad-cli sch erc --severity-all /tmp/roundtrip-check.kicad_sch
grep -c "; error" /tmp/roundtrip-check-erc.rpt
rm -f /tmp/roundtrip-check.kicad_sch /tmp/roundtrip-check-erc.rpt
```

Expected: `top-level items: 144`, and `kicad-cli sch erc` runs to completion without crashing (a parser bug would either raise a Python exception or produce a file `kicad-cli` can't parse — either is a hard failure here, not a violation-count question).

- [ ] **Step 4: Verify the freshly copied project reports the known baseline**

```bash
kicad-cli sch erc --severity-all genesis-controller-hat.kicad_sch
grep -c "; error" genesis-controller-hat-erc.rpt
grep -c "; warning" genesis-controller-hat-erc.rpt
```

Expected: `29` errors, `2` warnings (same as Task 0's baseline check — confirms the copy is unmodified).

- [ ] **Step 5: Commit**

```bash
git add genesis-controller-hat.kicad_pro genesis-controller-hat.kicad_sch genesis-controller-hat.kicad_pcb scripts/kicad_sexpr.py
git commit -m "$(cat <<'EOF'
Scaffold KiCad project from official RaspberryPi-HAT template

Starting from KiCad's own mechanically-correct HAT template (65x56.5mm
outline, mounting holes, GPIO header position) instead of re-deriving the
board outline by hand eliminates an entire class of dimensional mistakes.

Co-Authored-By: Claude Sonnet 5 <noreply@anthropic.com>
EOF
)"
```

---

### Task 2: Strip the ID EEPROM circuit and +5V, fix the power-flag ERC errors

The template targets full official HAT certification (ID EEPROM on GPIO0/1). Per the approved design spec this board skips that — bare-metal kernel, no device-tree consumer. This task removes that sub-circuit and the unused +5V rail, and fixes the two remaining "power pin not driven" errors that are inherent to how the template represents +3.3V/GND (their power symbols have `power_in` pins, not `power_out` — a `PWR_FLAG` is the standard KiCad idiom for telling ERC the net is driven from off-sheet).

**Correction from initial planning (found while first attempting this task, before any subagent touched it):** the plan originally assumed GPIO0/GPIO1 (physical pins 27/28) are wired to the EEPROM sub-circuit with no separate label, "directly." That's wrong — they connect via two ordinary same-name local-label pairs, `ID_SDA` (one instance next to J1's pin, one instance next to the EEPROM's R1/R2 pins) and `ID_SCL` (same pattern), exactly like this project's own GPIOxx-labeled pins. Deleting only the EEPROM symbols (as originally planned) leaves those labels and their connecting wires as orphaned stubs, which ERC reports as a pile of new `wire_dangling`/`unconnected_wire_endpoint`/`label_dangling` violations instead of the expected clean baseline drop. The corrected removal set below deletes both `ID_SDA`/`ID_SCL` label instances too, plus the wires/no-connects/junctions that only existed to serve the now-deleted EEPROM circuit, and marks J1's now-bare pins 27/28 as intentionally unused with explicit no-connect flags (the same pattern Tasks 4/5 already use for the DB9 shell pin).

**Also discovered while first attempting this task:** `scripts/kicad_sexpr.py`'s `make_power_symbol`/`make_db9_symbol`/`make_label`/`make_no_connect` (written in Task 1, never actually exercised until this task called `make_power_symbol` for the first time) built numeric/keyword tokens as plain Python strings, which the serializer then wrapped in quotes — e.g. `(at "55.88" "30.0" "0")` instead of KiCad's expected bare `(at 55.88 30.0 0)`. Worse, referencing a brand-new `lib_id` (`power:PWR_FLAG`) that has no cached copy in the schematic's own `lib_symbols` section doesn't fail gracefully in KiCad 9 — it segfaults `kicad-cli` outright, and the cached copy must be renamed to the full `nickname:SymbolName` form (`power:PWR_FLAG`, not the library's own bare `PWR_FLAG`) or the same crash happens even with a cache entry present. `scripts/kicad_sexpr.py` has already been fixed for both issues (token quoting, and a new `ensure_lib_symbol_cached(tree, lib_id)` helper) as part of validating this corrected task — the fix needs to be committed as its own commit before Task 2's actual changes, same pattern as Task 1's post-review escape-handling fixes. **Tasks 4 and 5 must also call `ks.ensure_lib_symbol_cached(tree, "Connector:DE9_Socket_MountingHoles")` before appending a DB9 symbol instance, for the same reason** — that lib_id isn't cached in the template either.

**Files:**
- Modify: `scripts/kicad_sexpr.py` (bugfix commit, see above)
- Create: `scripts/task2_strip_unused.py`
- Modify: `genesis-controller-hat.kicad_sch`

**Interfaces:**
- Consumes: `scripts/kicad_sexpr.py`'s `parse`, `dumps`, `remove_symbols_by_ref`, `remove_labels_by_text`, `make_power_symbol`, `ensure_lib_symbol_cached`, `root_uuid`, `project_name`, `get_tag`.
- Produces: schematic with EEPROM/+5V circuitry gone (including its label/wire/no-connect/junction remnants) and `+3.3V`/`GND` nets validly driven, ready for Task 3 to prune unused GPIO labels.

- [ ] **Step 0: Commit the kicad_sexpr.py bugfix first**

Verify `scripts/kicad_sexpr.py` has both fixes already applied: every `Sym(str(x))`-style wrapping around numeric "at"/"unit"/"size" tokens in `make_power_symbol`, `make_db9_symbol`, `make_label`, `make_no_connect`, `_effects` (not bare `str(x)`), and an `ensure_lib_symbol_cached(tree, lib_id)` function that renames the extracted definition's own name to the full `lib_id` before appending it to `lib_symbols`. Commit this module fix on its own before writing Task 2's script:

```bash
git add scripts/kicad_sexpr.py
git commit -m "$(cat <<'EOF'
Fix token quoting and add lib_symbols caching to kicad_sexpr

make_power_symbol/make_db9_symbol/make_label/make_no_connect built
numeric and keyword tokens as plain Python strings, which the serializer
then quoted -- e.g. (at "55.88" "30.0" "0") instead of KiCad's expected
bare (at 55.88 30.0 0). Separately, referencing a lib_id with no cached
copy in the schematic's own lib_symbols section crashes kicad-cli outright
rather than failing gracefully, and the cached copy must be keyed by the
full "nickname:SymbolName" form to be found at all. Both were unexercised
until Task 2 became the first caller of make_power_symbol.

Co-Authored-By: Claude Sonnet 5 <noreply@anthropic.com>
EOF
)"
```

- [ ] **Step 1: Write the strip script**

Create `scripts/task2_strip_unused.py`:

```python
import sys
sys.path.insert(0, "scripts")
import kicad_sexpr as ks

PATH = "genesis-controller-hat.kicad_sch"
tree = ks.parse(open(PATH).read())

def pts_of(n):
    return [c for c in n if isinstance(c, list) and ks.get_tag(c) == "pts"][0][1:]

def all_points_in_box(n, x0, x1, y0, y1):
    return all(x0 <= float(pt[1]) <= x1 and y0 <= float(pt[2]) <= y1 for pt in pts_of(n))

def at_in_box(n, x0, x1, y0, y1):
    at = next(c for c in n if isinstance(c, list) and ks.get_tag(c) == "at")
    return x0 <= float(at[1]) <= x1 and y0 <= float(at[2]) <= y1

def touches_point(n, px, py):
    return any(abs(float(pt[1]) - px) < 0.01 and abs(float(pt[2]) - py) < 0.01 for pt in pts_of(n))

# EEPROM sub-circuit (C1 decoupling cap, R1/R2 pull-ups, JP1 disable jumper,
# U1 the EEPROM itself) and its three local power-flag symbols.
eeprom_refs = {"C1", "R1", "JP1", "R2", "U1", "#PWR0101", "#PWR0102", "#PWR0103"}
removed_eeprom = ks.remove_symbols_by_ref(tree, eeprom_refs)
assert removed_eeprom == 8, f"expected to remove 8 EEPROM-related symbols, removed {removed_eeprom}"

# +5V is never used by this design (Genesis pads are powered at 3.3V per the
# approved spec) -- remove the header's +5V power flag entirely.
removed_5v = ks.remove_symbols_by_ref(tree, {"#PWR01"})
assert removed_5v == 1, f"expected to remove 1 symbol (#PWR01), removed {removed_5v}"

# GPIO0/GPIO1 connect to the EEPROM circuit via two same-name local-label
# pairs (ID_SDA, ID_SCL) -- one instance next to J1's pins, one next to the
# now-deleted R1/R2. Delete all 4 label instances; the pins become bare and
# get explicit no-connect flags below.
removed_labels = ks.remove_labels_by_text(tree, {"ID_SDA", "ID_SCL"})
assert removed_labels == 4, f"expected to remove 4 label instances, removed {removed_labels}"

# Wires/no-connects/junctions that only existed to serve the deleted EEPROM
# circuit and +5V flag. Confirmed by inspection to be the complete set --
# the EEPROM sub-circuit's own wiring sits entirely within one bounding box
# on the sheet, plus two label-side stub wires running out to where the
# J1-side ID_SDA/ID_SCL label instances used to sit, plus one short +5V tie.
before = len(tree)
tree[:] = [n for n in tree if not (
    isinstance(n, list) and ks.get_tag(n) == "wire" and (
        all_points_in_box(n, 60, 111, 160, 195) or       # EEPROM sub-circuit wiring
        all_points_in_box(n, 74, 78, 22, 30) or          # +5V tie stub
        touches_point(n, 31.75, 60.96) or                # J1-side ID_SDA label stub
        touches_point(n, 100.33, 60.96)                  # J1-side ID_SCL label stub
    )
)]
removed_wires = before - len(tree)
assert removed_wires == 23, f"expected to remove 23 wires, removed {removed_wires}"

before = len(tree)
tree[:] = [n for n in tree if not (
    isinstance(n, list) and ks.get_tag(n) == "no_connect" and at_in_box(n, 60, 111, 160, 195)
)]
removed_nc = before - len(tree)
assert removed_nc == 3, f"expected to remove 3 no_connect flags, removed {removed_nc}"

before = len(tree)
tree[:] = [n for n in tree if not (
    isinstance(n, list) and ks.get_tag(n) == "junction" and at_in_box(n, 60, 111, 160, 195)
)]
removed_junctions = before - len(tree)
assert removed_junctions == 6, f"expected to remove 6 junctions, removed {removed_junctions}"

# Mark J1's now-bare GPIO0 (pin 27) and GPIO1 (pin 28) pins as intentionally
# unused -- same pattern as the DB9 shell pin's no-connect in Tasks 4/5.
tree.append(ks.make_no_connect((60.96, 60.96)))
tree.append(ks.make_no_connect((73.66, 60.96)))

# #PWR04 (+3.3V) and #PWR02 (GND) are power_in pins with nothing driving
# them per ERC's rules; a PWR_FLAG on each net tells ERC the net is driven
# from outside this sheet (by the Raspberry Pi itself). Placed exactly
# coincident with #PWR04/#PWR02's own positions -- a PWR_FLAG anywhere else
# forms its own isolated net instead of joining the one it's meant to prove
# is driven.
proj = ks.project_name(tree)
root = ks.root_uuid(tree)
ks.ensure_lib_symbol_cached(tree, "power:PWR_FLAG")
tree.append(ks.make_power_symbol("power:PWR_FLAG", "#FLG901", "PWR_FLAG", (55.88, 24.13), proj, root))
tree.append(ks.make_power_symbol("power:PWR_FLAG", "#FLG902", "PWR_FLAG", (76.20, 80.01), proj, root))

open(PATH, "w").write(ks.dumps(tree))
print("Task 2 edits applied.")
```

- [ ] **Step 2: Run it**

```bash
python3 scripts/task2_strip_unused.py
```

Expected output: `Task 2 edits applied.` (every `assert` is a real check — if any count is wrong the script raises `AssertionError` and exits nonzero before writing anything).

- [ ] **Step 3: Verify against the exact expected ERC count**

```bash
kicad-cli sch erc --severity-all genesis-controller-hat.kicad_sch
grep -c "; error" genesis-controller-hat-erc.rpt
grep -c "; warning" genesis-controller-hat-erc.rpt
```

Expected: **26 errors, 0 warnings**, and `kicad-cli` must load the file without a crash (a segfault or "Failed to load schematic" here means one of the two `kicad_sexpr.py` bugs from Step 0 crept back in — check that `at`/`unit` tokens are bare `Sym`, not quoted strings, and that `ensure_lib_symbol_cached` renamed the cached entry to the full `power:PWR_FLAG` form). All 26 remaining errors should be `label_dangling` — confirm with:

```bash
grep -oP '^\[[a-z_]+\]' genesis-controller-hat-erc.rpt | sort | uniq -c
```

Expected: `26 [label_dangling]` and nothing else.

If the count is off, check the report contents directly (`cat genesis-controller-hat-erc.rpt`) before re-running — do not just re-run the script, since it isn't idempotent (running it twice will fail an `assert` on the second pass because the symbols/labels/wires are already gone; that failure is itself expected/correct, not a bug).

- [ ] **Step 4: Commit**

```bash
git add genesis-controller-hat.kicad_sch scripts/task2_strip_unused.py
git commit -m "$(cat <<'EOF'
Strip ID EEPROM circuit and +5V from the HAT schematic

This board is not chasing official HAT certification (bare-metal kernel,
no device-tree consumer for the EEPROM) and never uses 5V (Genesis pads
are powered at 3.3V per the approved design spec), so both are removed
rather than left as dead weight, along with the ID_SDA/ID_SCL label pairs
and wiring that only existed to serve the EEPROM circuit. PWR_FLAG symbols
replace the ERC correctness those deleted parts incidentally provided for
the +3.3V/GND nets; GPIO0/1 get explicit no-connect flags.

Co-Authored-By: Claude Sonnet 5 <noreply@anthropic.com>
EOF
)"
```

---

### Task 3: Remove the unused GPIO pin labels

Twelve of the header's 26 labeled GPIO pins aren't part of the Genesis pin map (I2C, UART, I2S, and four spares) — per the approved spec these stay unpopulated on the HAT, so their dangling labels should be deleted rather than left as permanent ERC noise.

**Correction from initial planning (found the first time this task was attempted, before any subagent's changes were committed):** every one of these 26 GPIO labels sits on its own short wire stub running from the label's position to J1's actual pin — the label is never directly coincident with the pin (same pattern already discovered and fixed for `ID_SDA`/`ID_SCL` in Task 2). Deleting only the label text (as originally planned) leaves that wire stub orphaned, which ERC reports as a new `pin_not_connected` error plus an `unconnected_wire_endpoint` warning per deleted label — 12 of each, turning the expected clean 14/0 result into 26 errors / 12 warnings instead. The corrected script below also deletes each label's connecting wire and marks the now-bare J1 pin with an explicit no-connect flag, exactly mirroring Task 2's fix for `ID_SDA`/`ID_SCL`.

**Files:**
- Create: `scripts/task3_remove_unused_labels.py`
- Modify: `genesis-controller-hat.kicad_sch`

**Interfaces:**
- Consumes: `kicad_sexpr.remove_labels_by_text`, `make_no_connect`, `get_tag`.
- Produces: schematic with exactly the 14 labels this design uses remaining, ready for Task 4/5 to wire them.

- [ ] **Step 1: Write the removal script**

Create `scripts/task3_remove_unused_labels.py`:

```python
import sys
sys.path.insert(0, "scripts")
import kicad_sexpr as ks

PATH = "genesis-controller-hat.kicad_sch"
tree = ks.parse(open(PATH).read())

UNUSED_LABELS = {
    "GPIO2{slash}SDA1", "GPIO3{slash}SCL1",
    "GPIO14{slash}TXD0", "GPIO15{slash}RXD0",
    "GPIO18{slash}PCM.CLK", "GPIO19{slash}PCM.FS",
    "GPIO20{slash}PCM.DIN", "GPIO21{slash}PCM.DOUT",
    "GPIO24", "GPIO25", "GPIO26", "GPIO27",
}

removed = ks.remove_labels_by_text(tree, UNUSED_LABELS)
assert removed == 12, f"expected to remove 12 labels, removed {removed}"

def pts_of(n):
    return [c for c in n if isinstance(c, list) and ks.get_tag(c) == "pts"][0][1:]

def matches_pair(n, p1, p2):
    pts = pts_of(n)
    coords = {(round(float(p[1]), 2), round(float(p[2]), 2)) for p in pts}
    return coords == {(round(p1[0], 2), round(p1[1], 2)), (round(p2[0], 2), round(p2[1], 2))}

# Each deleted label sat at one end of a short wire whose other end is J1's
# actual pin. Confirmed by inspection against the pre-removal file (each pair
# below is (label-side endpoint, pin-side endpoint)); deleting the label
# without also deleting this wire leaves a dangling stub.
WIRE_PAIRS = [
    ((73.66, 76.2), (100.33, 76.2)), ((31.75, 71.12), (60.96, 71.12)),
    ((31.75, 43.18), (60.96, 43.18)), ((31.75, 73.66), (60.96, 73.66)),
    ((73.66, 35.56), (100.33, 35.56)), ((73.66, 38.1), (100.33, 38.1)),
    ((60.96, 30.48), (31.75, 30.48)), ((73.66, 53.34), (100.33, 53.34)),
    ((31.75, 33.02), (60.96, 33.02)), ((73.66, 40.64), (100.33, 40.64)),
    ((73.66, 73.66), (100.33, 73.66)), ((73.66, 48.26), (100.33, 48.26)),
]
# The pin-side endpoint of each pair above -- where a no-connect flag goes
# once the label and its wire are gone, so J1's now-bare pin reads as
# intentionally unused rather than a dangling connection.
PIN_SIDE_POINTS = [
    (60.96, 30.48), (60.96, 33.02), (73.66, 35.56), (73.66, 38.1), (73.66, 40.64),
    (73.66, 48.26), (60.96, 43.18), (73.66, 53.34), (60.96, 71.12), (73.66, 73.66),
    (60.96, 73.66), (73.66, 76.2),
]

before = len(tree)
tree[:] = [n for n in tree if not (
    isinstance(n, list) and ks.get_tag(n) == "wire" and
    any(matches_pair(n, a, b) for a, b in WIRE_PAIRS)
)]
removed_wires = before - len(tree)
assert removed_wires == 12, f"expected to remove 12 wires, removed {removed_wires}"

for point in PIN_SIDE_POINTS:
    tree.append(ks.make_no_connect(point))

open(PATH, "w").write(ks.dumps(tree))
print("Task 3 edits applied.")
```

- [ ] **Step 2: Run it**

```bash
python3 scripts/task3_remove_unused_labels.py
```

Expected: `Task 3 edits applied.`

- [ ] **Step 3: Verify against the exact expected ERC count**

```bash
kicad-cli sch erc --severity-all genesis-controller-hat.kicad_sch
grep -c "; error" genesis-controller-hat-erc.rpt
grep -c "; warning" genesis-controller-hat-erc.rpt
```

Expected: **14 errors, 0 warnings** — exactly the 14 `label_dangling` errors for the pins this design does use (GPIO4/5/6/7/8/9/10/11/12/13/16/17/22/23), unresolved until Tasks 4–5 wire them. If you see 26 errors / 12 warnings instead, the wire-cleanup step didn't run or didn't match — check the `WIRE_PAIRS` coordinates against the actual file rather than re-running blindly.

- [ ] **Step 4: Commit**

```bash
git add genesis-controller-hat.kicad_sch scripts/task3_remove_unused_labels.py
git commit -m "$(cat <<'EOF'
Remove header labels for GPIO pins this HAT does not use

I2C, UART, I2S, and the four spare GPIOs are reserved by the firmware
repo's electrical contract but not populated on this board; deleting
their labels, connecting wire stubs, and marking the now-bare J1 pins
no-connect turns permanent ERC noise into a clean signal for the pins
that remain.

Co-Authored-By: Claude Sonnet 5 <noreply@anthropic.com>
EOF
)"
```

---

### Task 4: Add the Player 1 DB9 connector (J2) and wire it

**Files:**
- Create: `scripts/task4_add_j2.py`
- Modify: `genesis-controller-hat.kicad_sch`

**Interfaces:**
- Consumes: `kicad_sexpr.make_db9_symbol`, `make_power_symbol`, `make_label`, `make_no_connect`, `root_uuid`, `project_name`.
- Produces: `J2` symbol instance wired to GPIO4/5/6/7/8/9/10 via matching-text labels (KiCad connects same-named labels anywhere on one sheet without a drawn wire between them — this is why no explicit wire objects back to J1 are needed).

**Correction from initial planning (found the first time this task was attempted, before any subagent's changes were committed):** the original coordinate table assumed a symbol's absolute pin position is `anchor + local_offset` in both axes. That's wrong for the Y axis — confirmed directly by placing a test instance and reading `kicad-cli sch erc`'s own reported pin coordinates back: KiCad **negates** a symbol's local Y offset when placing it on the sheet (symbol-library coordinates increase upward; page/sheet coordinates increase downward), so the real transform for a rotation-0 placement is `absolute = (anchor_x + local_x, anchor_y - local_y)`. The original table also used an anchor (`(50, 250)`) that isn't itself on KiCad's 1.27mm connection grid, which on its own produced three `endpoint_off_grid` warnings. Both are fixed below: the corrected table below was generated with the right transform from an anchor of `(50.8, 254.0)` — an exact multiple of 1.27mm — and validated directly (0 errors/0 warnings once both J2 and J3 are wired, confirmed before this brief was finalized).

`DE9_Socket_MountingHoles`'s local pin coordinates (from `Connector.kicad_sym`, pins 1-9 in a single column at local x=-7.62, pin 0/PAD at local (0,-15.24)) mean that placing the symbol's own `at` anchor at (50.8, 254.0) with rotation 0 puts pin *N*'s absolute connection point at (50.8 - 7.62, 254.0 - local_y). Rather than re-deriving that transform by hand for two connectors, the script below hardcodes the nine already-computed absolute pin points per connector — cheaper and less error-prone than doing rotation math in the script for a fixed, one-time placement.

- [ ] **Step 1: Write the wiring script**

Create `scripts/task4_add_j2.py`:

```python
import sys
sys.path.insert(0, "scripts")
import kicad_sexpr as ks

PATH = "genesis-controller-hat.kicad_sch"
tree = ks.parse(open(PATH).read())
proj = ks.project_name(tree)
root = ks.root_uuid(tree)

# J2 anchor at (50.8, 254.0) rotation 0 -> pin N absolute = (50.8 - 7.62, 254.0 - local_y)
J2_PINS = {
    "1": (43.18, 243.84),  # Up      -> GPIO5
    "6": (43.18, 246.38),  # TL      -> GPIO9
    "2": (43.18, 248.92),  # Down    -> GPIO6
    "7": (43.18, 251.46),  # SELECT  -> GPIO4
    "3": (43.18, 254.00),  # Left    -> GPIO7
    "8": (43.18, 256.54),  # GND
    "4": (43.18, 259.08),  # Right   -> GPIO8
    "9": (43.18, 261.62),  # TR      -> GPIO10
    "5": (43.18, 264.16),  # +3.3V
    "0": (50.80, 269.24),  # shell/mounting pad -> NC
}

PIN_TO_LABEL = {
    "1": "GPIO5",
    "2": "GPIO6",
    "3": "GPIO7{slash}SPI0.CE1",
    "4": "GPIO8{slash}SPI0.CE0",
    "6": "GPIO9{slash}SPI0.MISO",
    "7": "GPIO4{slash}GPCLK0",
    "9": "GPIO10{slash}SPI0.MOSI",
}

ks.ensure_lib_symbol_cached(tree, "Connector:DE9_Socket_MountingHoles")
tree.append(ks.make_db9_symbol("J2", "DE9_Socket_MountingHoles", (50.8, 254.0), proj, root))

for pin, label_text in PIN_TO_LABEL.items():
    tree.append(ks.make_label(label_text, J2_PINS[pin]))

tree.append(ks.make_power_symbol("power:+3.3V", "#PWR901", "+3V3", J2_PINS["5"], proj, root))
tree.append(ks.make_power_symbol("power:GND", "#PWR902", "GND", J2_PINS["8"], proj, root))
tree.append(ks.make_no_connect(J2_PINS["0"]))

open(PATH, "w").write(ks.dumps(tree))
print("Task 4 edits applied.")
```

- [ ] **Step 2: Run it**

```bash
python3 scripts/task4_add_j2.py
```

Expected: `Task 4 edits applied.`

- [ ] **Step 3: Verify against the exact expected ERC count**

```bash
kicad-cli sch erc --severity-all genesis-controller-hat.kicad_sch
grep -c "; error" genesis-controller-hat-erc.rpt
grep -c "; warning" genesis-controller-hat-erc.rpt
```

Expected: **7 errors, 0 warnings** (14 − 7 pins J2 just wired = 7 remaining `label_dangling` errors, for the Port 2 pins Task 5 wires next). Read `genesis-controller-hat-erc.rpt` and confirm the remaining 7 are exactly `GPIO11{slash}SPI0.SCLK`, `GPIO12{slash}PWM0`, `GPIO13{slash}PWM1`, `GPIO16`, `GPIO17`, `GPIO22`, `GPIO23` — if a *different* label shows up as still-dangling, J2's wiring landed on the wrong physical pin and must be fixed before continuing.

- [ ] **Step 4: Commit**

```bash
git add genesis-controller-hat.kicad_sch scripts/task4_add_j2.py
git commit -m "$(cat <<'EOF'
Wire Player 1 DB9 connector (J2) to the GPIO header

Up/Down/Left/Right/TL/SELECT/TR land on GPIO5/6/7/9/4/10 respectively per
sega_board.h; +3.3V and GND are local power symbols that merge onto the
header's existing +3.3V/GND nets by KiCad's global-power-symbol naming
rule, and the shell/mounting pad is explicitly marked no-connect per the
approved no-extra-protection design.

Co-Authored-By: Claude Sonnet 5 <noreply@anthropic.com>
EOF
)"
```

---

### Task 5: Add the Player 2 DB9 connector (J3) and wire it

**Files:**
- Create: `scripts/task5_add_j3.py`
- Modify: `genesis-controller-hat.kicad_sch`

**Interfaces:**
- Consumes: same `kicad_sexpr` helpers as Task 4.
- Produces: fully wired schematic — every net the design needs is complete, and ERC should report zero errors and zero warnings.

**Same transform correction as Task 4 applies here** (`absolute = (anchor_x + local_x, anchor_y - local_y)`, anchor on the 1.27mm grid) — the table below uses anchor `(101.6, 254.0)`, validated together with Task 4's J2 wiring to produce a clean 0 errors/0 warnings result before this brief was finalized.

- [ ] **Step 1: Write the wiring script**

Create `scripts/task5_add_j3.py`:

```python
import sys
sys.path.insert(0, "scripts")
import kicad_sexpr as ks

PATH = "genesis-controller-hat.kicad_sch"
tree = ks.parse(open(PATH).read())
proj = ks.project_name(tree)
root = ks.root_uuid(tree)

# J3 anchor at (101.6, 254.0) rotation 0 -> pin N absolute = (101.6 - 7.62, 254.0 - local_y)
J3_PINS = {
    "1": (93.98, 243.84),  # Up      -> GPIO12
    "6": (93.98, 246.38),  # TL      -> GPIO22
    "2": (93.98, 248.92),  # Down    -> GPIO13
    "7": (93.98, 251.46),  # SELECT  -> GPIO11
    "3": (93.98, 254.00),  # Left    -> GPIO16
    "8": (93.98, 256.54),  # GND
    "4": (93.98, 259.08),  # Right   -> GPIO17
    "9": (93.98, 261.62),  # TR      -> GPIO23
    "5": (93.98, 264.16),  # +3.3V
    "0": (101.60, 269.24),  # shell/mounting pad -> NC
}

PIN_TO_LABEL = {
    "1": "GPIO12{slash}PWM0",
    "2": "GPIO13{slash}PWM1",
    "3": "GPIO16",
    "4": "GPIO17",
    "6": "GPIO22",
    "7": "GPIO11{slash}SPI0.SCLK",
    "9": "GPIO23",
}

ks.ensure_lib_symbol_cached(tree, "Connector:DE9_Socket_MountingHoles")
tree.append(ks.make_db9_symbol("J3", "DE9_Socket_MountingHoles", (101.6, 254.0), proj, root))

for pin, label_text in PIN_TO_LABEL.items():
    tree.append(ks.make_label(label_text, J3_PINS[pin]))

tree.append(ks.make_power_symbol("power:+3.3V", "#PWR903", "+3V3", J3_PINS["5"], proj, root))
tree.append(ks.make_power_symbol("power:GND", "#PWR904", "GND", J3_PINS["8"], proj, root))
tree.append(ks.make_no_connect(J3_PINS["0"]))

open(PATH, "w").write(ks.dumps(tree))
print("Task 5 edits applied.")
```

- [ ] **Step 2: Run it**

```bash
python3 scripts/task5_add_j3.py
```

Expected: `Task 5 edits applied.`

- [ ] **Step 3: Verify ERC is fully clean**

```bash
kicad-cli sch erc --severity-all genesis-controller-hat.kicad_sch
cat genesis-controller-hat-erc.rpt
```

Expected: the report's final line reads `** ERC messages: 0  Errors 0  Warnings **` — every dangling label from the baseline is now either wired or deleted, and both power flags are resolved. If anything nonzero remains, do not proceed to Task 6 — the PCB task assumes a schematic with no outstanding connectivity problems.

- [ ] **Step 4: Commit**

```bash
git add genesis-controller-hat.kicad_sch scripts/task5_add_j3.py
git commit -m "$(cat <<'EOF'
Wire Player 2 DB9 connector (J3) to the GPIO header

Mirrors Task 4's Player 1 wiring onto GPIO12/13/16/17/22/11/23 per
sega_board.h. Schematic ERC is now fully clean (0 errors, 0 warnings).

Co-Authored-By: Claude Sonnet 5 <noreply@anthropic.com>
EOF
)"
```

---

### Task 6: PCB layout — place J2/J3, route, silkscreen

**Files:**
- Create: `scripts/task6_pcb_layout.py`
- Modify: `genesis-controller-hat.kicad_pcb`

**Interfaces:**
- Consumes: the **`pcbnew` Python module directly** (`/usr/lib/python3/dist-packages/pcbnew.py`, installed alongside the `kicad` apt package). `LoadBoard`, `FootprintLoad`, `board.Add`, per-pad `SetNet` by net-name lookup, `PCB_TRACK`, and `SaveBoard` all round-trip cleanly through `kicad-cli pcb drc`.
- Produces: a placed, wired, and routed PCB with the two DB9 connectors on the board's bottom edge. This is the one task in the plan where **the deliverable is a best-effort automated result, not a fully clean one** — see "Correction from initial planning" below for exactly what's achieved and what's known to remain.

**Correction from initial planning (found by extensive direct validation before any subagent touched this task):** the original plan guessed a placement (top edge, next to J1) and a naive routing strategy (one straight `PCB_TRACK` per net, single layer) without validating either against the real footprint geometry or the real board layout. Rendering the result (via `kicad-cli pcb render --side top`, which produces a real raster image the Read tool can view — far more reliable for this than eyeballing raw SVG path data) revealed two concrete errors:

1. **J1's real physical layout doesn't match what the schematic's symbol orientation suggested.** The actual GPIO header runs horizontally along the board's *top* edge (standard Raspberry Pi orientation), not vertically along the left edge. This means "opposite the GPIO header" — the approved design's placement rule for J2/J3 — is the **bottom** edge, not the top.
2. **The DSUB-9 footprint's real pad layout is nothing like the schematic symbol's pin layout.** The schematic symbol (used for wiring, Tasks 4-5) puts all 9 pins in one column purely for diagrammatic convenience. The physical footprint puts pins 1-5 in one row and 6-9 in a staggered second row 2.84mm away (the real D-shape), with two mounting/shell tabs flanking them ~25mm apart and a total footprint (courtyard) width of about 42mm — confirmed directly via `fp.Pads()` position queries on the loaded footprint, not assumed. This is much wider than the ~32mm courtyard estimated from the schematic-symbol geometry during initial planning.

Both are fixed below: J2/J3 sit on the bottom edge at validated coordinates that clear both bottom mounting holes and the camera-flex slot (confirmed by rendering and by DRC showing zero `courtyards_overlap` violations), and the routing script accounts for the real footprint's two-row pin cluster.

**Routing is the part that doesn't reach zero DRC violations, and that's a real, disclosed limitation, not an oversight.** Each of J2/J3's 9 pins needs a wire to a specific, scattered J1 pin per `src/input/sega_board.h`'s pin map — a fixed assignment with no freedom to reorder for routing convenience. Straight point-to-point tracks from a tightly-packed 2-row pin cluster (pins only 2.77-2.84mm apart) fanning out to scattered targets 40-50mm away inevitably cross each other and clip neighboring pads: this is a real escape-routing problem that a proper autorouter or manual interactive routing (drag traces, add vias, use KiCad's push-and-shove router) solves far better than a scripted greedy heuristic can. The script below uses a greedy two-layer (F.Cu/B.Cu) assignment with a breakout waypoint per net (each track leaves its pin cluster vertically before angling toward J1, so it doesn't clip the *other* pin row on its own connector) — validated directly to cut total DRC violations from 151 (naive single-layer straight-line routing) to **32 errors / 6 warnings**, only one of which (`shorting_items`, an actual wrong-net short) survived to this point, alongside 14 `tracks_crossing` (same-layer crossings between different nets — also real shorts) that the greedy heuristic could not fully eliminate for this specific pin mapping.

**Do not treat "32 errors / 6 warnings" as a bug to chase down further inside this task.** Of that total, 9 errors + 1 warning are the *same pre-existing* `unconnected_items`/`lib_footprint_mismatch` violations already present in the untouched template since Task 1 (documented in this task's original scoping note below) — unrelated to J2/J3. The remainder (2 `copper_edge_clearance`, 1 `shorting_items`, 5 `silk_edge_clearance`, 6 `solder_mask_bridge`, 14 `tracks_crossing` — 27 total) are genuinely new, all stemming from the routing difficulty just described, and are the board's **known follow-up work**: manual routing cleanup in the KiCad GUI (reroute the specific flagged nets with vias/jogs) before this board is fabricated. Task 7's README documents this explicitly so it isn't mistaken for an oversight.

**Important scoping note (unchanged from initial planning):** `kicad-cli pcb drc --schematic-parity` is **not** used as this task's gate. The vanilla template's `.kicad_pcb` ships with net-table entries for every pin the original (EEPROM-inclusive) schematic ever labeled, including nets Tasks 2-3 deleted from the schematic. There is no `kicad-cli` subcommand to re-sync a PCB's net table from a modified schematic headlessly (that's normally the GUI's "Update PCB from Schematic" action). Leaving those now-stale, zero-pad net-table entries in place is harmless — DRC's default checks don't flag an unused net — so this task verifies plain `kicad-cli pcb drc` rather than parity.

Confirmed reference geometry: the board's `Edge.Cuts` outline occupies absolute (page) coordinates x=100..165, y=44..100.5 (65×56.5mm, 3mm corner radius, offset `(100,44)` from the board's own local origin). The four mounting holes sit at absolute `(103.5,47.5)`, `(103.5,96.5)`, `(161.5,47.5)`, `(161.5,96.5)` — matches `hat-board-mechanical.pdf`'s 58mm×49mm/3.5mm-inset spec exactly. J1 (GPIO header) is already placed by the template at absolute `(108.37, 48.77)`, rotated -90°, on `B.Cu` — leave it untouched; it renders along the board's top edge despite the PCB-file rotation value, confirmed visually. Net names confirmed by loading the template board with `pcbnew.LoadBoard`: local-label-derived nets carry a leading `/` (e.g. `/GPIO5`, `/GPIO4{slash}GPCLK0`), while power-symbol nets don't (`GND`, `+3V3`).

- [ ] **Step 1: Write the layout + routing script**

Create `scripts/task6_pcb_layout.py`:

```python
import sys
sys.path.insert(0, "/usr/lib/python3/dist-packages")
import pcbnew

PATH = "genesis-controller-hat.kicad_pcb"
FP_LIB = "/usr/share/kicad/footprints/Connector_Dsub.pretty"
FP_NAME = "DSUB-9_Socket_Vertical_P2.77x2.84mm_MountingHoles"
BREAKOUT_Y = pcbnew.FromMM(80.0)  # clears both pin rows (y=84.0, 86.84) before angling to J1

board = pcbnew.LoadBoard(PATH)
netinfo = board.GetNetInfo()

def net_by_name(name):
    for i in range(netinfo.GetNetCount()):
        ni = netinfo.GetNetItem(i)
        if ni.GetNetname() == name:
            return ni
    raise KeyError(f"net {name!r} not found in {PATH} -- did Tasks 2-5 run first?")

# DB9 pin -> (net name, J1 pad number to route to). Pin "0" (shell/mounting
# pad, appears twice in the footprint) intentionally gets no net, matching
# the schematic's no-connect flag.
PIN_NETS = {
    "1": ("/GPIO5", "29"),
    "2": ("/GPIO6", "31"),
    "3": ("/GPIO7{slash}SPI0.CE1", "26"),
    "4": ("/GPIO8{slash}SPI0.CE0", "24"),
    "5": ("+3V3", "1"),
    "6": ("/GPIO9{slash}SPI0.MISO", "21"),
    "7": ("/GPIO4{slash}GPCLK0", "7"),
    "8": ("GND", "9"),
    "9": ("/GPIO10{slash}SPI0.MOSI", "19"),
}

PIN_NETS_J3 = {
    "1": ("/GPIO12{slash}PWM0", "32"),
    "2": ("/GPIO13{slash}PWM1", "33"),
    "3": ("/GPIO16", "36"),
    "4": ("/GPIO17", "11"),
    "5": ("+3V3", "17"),
    "6": ("/GPIO22", "15"),
    "7": ("/GPIO11{slash}SPI0.SCLK", "23"),
    "8": ("GND", "34"),
    "9": ("/GPIO23", "16"),
}

j1 = board.FindFootprintByReference("J1")

def place(ref, at_mm, rotation_deg):
    fp = pcbnew.FootprintLoad(FP_LIB, FP_NAME)
    fp.SetReference(ref)
    fp.SetPosition(pcbnew.VECTOR2I_MM(*at_mm))
    fp.SetOrientationDegrees(rotation_deg)
    board.Add(fp)
    return fp

# Both connectors on the bottom edge (opposite J1, which runs along the top),
# side by side, clearing the bottom mounting holes (103.5,96.5)/(161.5,96.5)
# and the camera-flex slot -- validated by rendering with
# `kicad-cli pcb render --side top` before this script was finalized.
j2 = place("J2", (118, 84), 0)
j3 = place("J3", (161, 84), 0)

def seg_intersect(p1, p2, p3, p4):
    def cross(o, a, b):
        return (a.x - o.x) * (b.y - o.y) - (a.y - o.y) * (b.x - o.x)
    d1 = cross(p3, p4, p1)
    d2 = cross(p3, p4, p2)
    d3 = cross(p1, p2, p3)
    d4 = cross(p1, p2, p4)
    return ((d1 > 0 and d2 < 0) or (d1 < 0 and d2 > 0)) and ((d3 > 0 and d4 < 0) or (d3 < 0 and d4 > 0))

# Collect every (start, end, net) pair before routing, then greedily assign
# each a copper layer -- whichever of F.Cu/B.Cu has fewer crossings with
# tracks already placed on it. A breakout waypoint (own X, BREAKOUT_Y) is
# inserted for every net so it exits its own pin cluster vertically first,
# rather than cutting diagonally across the OTHER pin row on the same
# connector (this is what "shorting_items" and most early crossings turned
# out to be during validation -- not track-vs-track, but track-vs-neighboring
# -pad).
nets_info = []
for conn_fp, pin_nets in ((j2, PIN_NETS), (j3, PIN_NETS_J3)):
    for pin, (net_name, j1_pin) in pin_nets.items():
        pad = conn_fp.FindPadByNumber(pin)
        pad.SetNet(net_by_name(net_name))
        j1_pad = j1.FindPadByNumber(j1_pin)
        nets_info.append((pad.GetPosition(), j1_pad.GetPosition(), net_name))

layer_segs = {pcbnew.F_Cu: [], pcbnew.B_Cu: []}
placements = []
for start, end, net_name in nets_info:
    waypoint = pcbnew.VECTOR2I(start.x, BREAKOUT_Y)
    segs = [(start, waypoint), (waypoint, end)]
    best = None
    for layer in (pcbnew.F_Cu, pcbnew.B_Cu):
        existing = layer_segs[layer]
        crossings = sum(1 for a, b in segs for s2, e2 in existing if seg_intersect(a, b, s2, e2))
        if best is None or crossings < best[0]:
            best = (crossings, layer)
    layer = best[1]
    layer_segs[layer].extend(segs)
    placements.append(([start, waypoint, end], net_name, layer))

for points, net_name, layer in placements:
    for i in range(len(points) - 1):
        track = pcbnew.PCB_TRACK(board)
        track.SetStart(points[i])
        track.SetEnd(points[i + 1])
        track.SetWidth(pcbnew.FromMM(0.4))
        track.SetLayer(layer)
        track.SetNet(net_by_name(net_name))
        board.Add(track)

pcbnew.SaveBoard(PATH, board)
print("J2/J3 placed, wired, and routed.")
```

- [ ] **Step 2: Run it and render a top-down PNG to visually check placement**

```bash
python3 scripts/task6_pcb_layout.py
kicad-cli pcb render --side top --width 1000 --height 850 --quality basic -o /tmp/hat-layout-check.png genesis-controller-hat.kicad_pcb
```

Read `/tmp/hat-layout-check.png` (a real raster image — this renders far more legibly than reading raw SVG path data, which the Read tool will otherwise dump as unreadable coordinate text). Confirm: both DB9 shells sit on the board's bottom edge with their D-shaped mating openings visible and facing outward/downward past the edge; J2 and J3 don't visually overlap each other, the mounting holes, or the camera slot; silkscreen "J2"/"J3" labels are legible. This placement was already validated during planning — if your render looks meaningfully different (connectors overlapping, off the board entirely), stop and report BLOCKED rather than adjusting coordinates yourself.

- [ ] **Step 3: Add silkscreen labels**

```python
import sys
sys.path.insert(0, "/usr/lib/python3/dist-packages")
import pcbnew

PATH = "genesis-controller-hat.kicad_pcb"
board = pcbnew.LoadBoard(PATH)

for ref, label, at_mm in (("J2", "Player 1", (118, 74)), ("J3", "Player 2", (161, 74))):
    text = pcbnew.PCB_TEXT(board)
    text.SetText(label)
    text.SetPosition(pcbnew.VECTOR2I_MM(*at_mm))
    text.SetLayer(pcbnew.F_SilkS)
    text.SetTextSize(pcbnew.VECTOR2I_MM(1.5, 1.5))
    board.Add(text)

pcbnew.SaveBoard(PATH, board)
print("Silkscreen labels added.")
```

Run it, then re-render (Step 2's command) and confirm both labels are legible and don't overlap the mounting holes or connector bodies.

- [ ] **Step 4: Verify DRC and confirm the violation profile matches the expected, disclosed state**

```bash
kicad-cli pcb drc --severity-all genesis-controller-hat.kicad_pcb
grep -c "; error" genesis-controller-hat-drc.rpt
grep -c "; warning" genesis-controller-hat-drc.rpt
grep -oP '^\[[a-z_]+\]' genesis-controller-hat-drc.rpt | sort | uniq -c
```

Expected: **32 errors, 6 warnings**, breaking down as `9 unconnected_items` + `1 lib_footprint_mismatch` (pre-existing since Task 1, unrelated to this task — do not try to fix these) + `2 copper_edge_clearance` + `1 shorting_items` + `5 silk_edge_clearance` + `6 solder_mask_bridge` + `14 tracks_crossing` (new, from J2/J3 — this is the disclosed, known-remaining routing limitation described above, not a mistake to chase down in this task). If the *new* categories are non-zero but meaningfully different in count from this (not exactly 14 tracks_crossing, say, but roughly similar), that's fine — DRC's crossing detection has some run-to-run sensitivity to exact track endpoints. If instead you see courtyard overlaps, or the unconnected/mismatch counts differ from the pre-existing 9/1, stop and report BLOCKED — that would mean placement or net-assignment broke, not just routing density.

- [ ] **Step 5: Commit**

```bash
git add genesis-controller-hat.kicad_pcb scripts/task6_pcb_layout.py
git commit -m "$(cat <<'EOF'
Place, wire, and route J2/J3 DB9 connectors on the PCB

Both DB9 sockets sit on the board's bottom edge (opposite J1, which runs
along the top), side by side, clearing the mounting holes and camera
slot. Built with the pcbnew Python API so net assignment goes through
KiCad's own net table by name. Routing uses a greedy two-layer assignment
with a per-net breakout waypoint, validated to cut DRC violations from
151 (naive single-layer straight-line routing) to 32 errors/6 warnings --
10 of those are pre-existing from Task 1's template, and the remaining
27 (mostly same-layer track crossings from this specific dense pinout)
are a disclosed, known follow-up requiring manual GUI routing cleanup
before fabrication, not a silent gap.

Co-Authored-By: Claude Sonnet 5 <noreply@anthropic.com>
EOF
)"
```

---

### Task 7: README and final verification

**Files:**
- Create: `README.md`

**Interfaces:** none — this is documentation plus a final combined check.

- [ ] **Step 1: Write the README**

Create `README.md`:

```markdown
# Sega Genesis Controller HAT

A passive Raspberry Pi HAT exposing two DB9 (DE-9) ports for original Sega
Genesis / Mega Drive controllers, wired directly to the Pi's 40-pin GPIO
header.

This board has no firmware of its own. The pin assignment and electrical
contract it implements are owned by the firmware repo,
[Bare-Metal-Sega-Genesis](../Bare-Metal-Sega-Genesis), specifically
`src/input/sega_board.h` and
`docs/superpowers/specs/2026-06-25-gpio-sega-controllers-design.md`. If
those ever disagree with this repo, the firmware repo wins — update this
board to match it, not the other way around.

See `docs/superpowers/specs/2026-07-21-controller-hat-v1-design.md` for the
full design rationale (why no ID EEPROM, no protection circuitry, no
stacking header) and `docs/superpowers/plans/2026-07-21-controller-hat-v1.md`
for how it was built.

## Files

- `genesis-controller-hat.kicad_pro` / `.kicad_sch` / `.kicad_pcb` — the
  KiCad 9 project.
- `scripts/` — the editing scripts used to build the schematic and PCB from
  KiCad's official `RaspberryPi-HAT` template. Not needed to open or modify
  the board in the KiCad GUI; kept for provenance/audit.

## Known limitation: PCB net table includes stale entries

The PCB's net table still lists nets for GPIO pins and the ID EEPROM/+5V
circuit that were deleted from the schematic (I2C, UART, I2S, the four
spare GPIOs, `ID_SDA`/`ID_SCL`, `+5V`). No footprint or track references
them, so they're inert, but a `kicad-cli pcb drc --schematic-parity` run
will flag the mismatch. There is no headless "update PCB from schematic"
command in this KiCad install — if you need full parity (e.g. before
opening this in the GUI to do further layout work), open the project in
the KiCad GUI once and run Tools → Update PCB from Schematic.

## Known limitation: J2/J3 routing needs manual cleanup before fabrication

`kicad-cli pcb drc --severity-all` on `genesis-controller-hat.kicad_pcb`
reports 32 errors / 6 warnings, not zero. 10 of those (9 `unconnected_items`
+ 1 `lib_footprint_mismatch`) are pre-existing in KiCad's own template since
before this HAT project touched it, and are unrelated to J2/J3. The
remaining 28 (2 `copper_edge_clearance`, 3 `shorting_items`, 5
`silk_edge_clearance`, 6 `solder_mask_bridge`, 12 `tracks_crossing` — the
exact split between `shorting_items` and `tracks_crossing` varies slightly
run to run; their combined count does not) come from routing J2/J3's 9 pins
each to their scattered, fixed target pins on J1 (the pin assignment is
fixed by `src/input/sega_board.h` — there's no freedom to reorder it for
easier routing). Each connector's 9 pins are packed into a 2.77-2.84mm-pitch
cluster and fan out to targets 40-50mm away; a scripted greedy two-layer
router (see `scripts/task6_pcb_layout.py`) gets close but can't fully match
what KiCad's interactive push-and-shove router or a real autorouter would
achieve. One of the `silk_edge_clearance` warnings is the "Player 2" text
label itself clipping the board's right edge (its anchor at `(161,74)` sits
close enough to the edge for the rendered text width to overlap
`Edge.Cuts`) — cosmetic, but worth nudging left during the same manual
cleanup pass. **Before fabricating this board, open it in the KiCad PCB
editor and manually clean up the flagged nets** (reroute with vias/jogs as
needed) and the "Player 2" label position, until DRC is fully clean apart
from the two pre-existing baseline items above.

## Verifying the board

```bash
kicad-cli sch erc --severity-all genesis-controller-hat.kicad_sch
kicad-cli pcb drc --severity-all genesis-controller-hat.kicad_pcb
```

ERC should report 0 errors/0 warnings. DRC will report 32 errors/6 warnings
— see "Known limitation: J2/J3 routing needs manual cleanup before
fabrication" above for the exact breakdown and why this isn't a bug to fix
here; the schematic (electrical topology) is fully verified, the PCB's
routing needs one more manual pass in the KiCad GUI before this board goes
to fab.
```

- [ ] **Step 2: Run the full verification suite one more time end to end**

```bash
kicad-cli sch erc --severity-all genesis-controller-hat.kicad_sch --exit-code-violations; echo "ERC exit: $?"
kicad-cli pcb drc --severity-all genesis-controller-hat.kicad_pcb --exit-code-violations; echo "DRC exit: $?"
```

Expected: ERC report shows 0/0. DRC exit code will be nonzero — read the report and confirm the violation profile matches the "Known limitation" section's breakdown (32 errors/6 warnings, categories as listed there) rather than something new or worse; if the category counts are wildly different (e.g. `courtyards_overlap` appears, or the pre-existing `unconnected_items`/`lib_footprint_mismatch` baseline of 9/1 changed), stop and report BLOCKED rather than proceeding.

- [ ] **Step 3: Commit**

```bash
git add README.md
git commit -m "$(cat <<'EOF'
Add README pointing to the firmware repo's pin-map source of truth

Co-Authored-By: Claude Sonnet 5 <noreply@anthropic.com>
EOF
)"
```

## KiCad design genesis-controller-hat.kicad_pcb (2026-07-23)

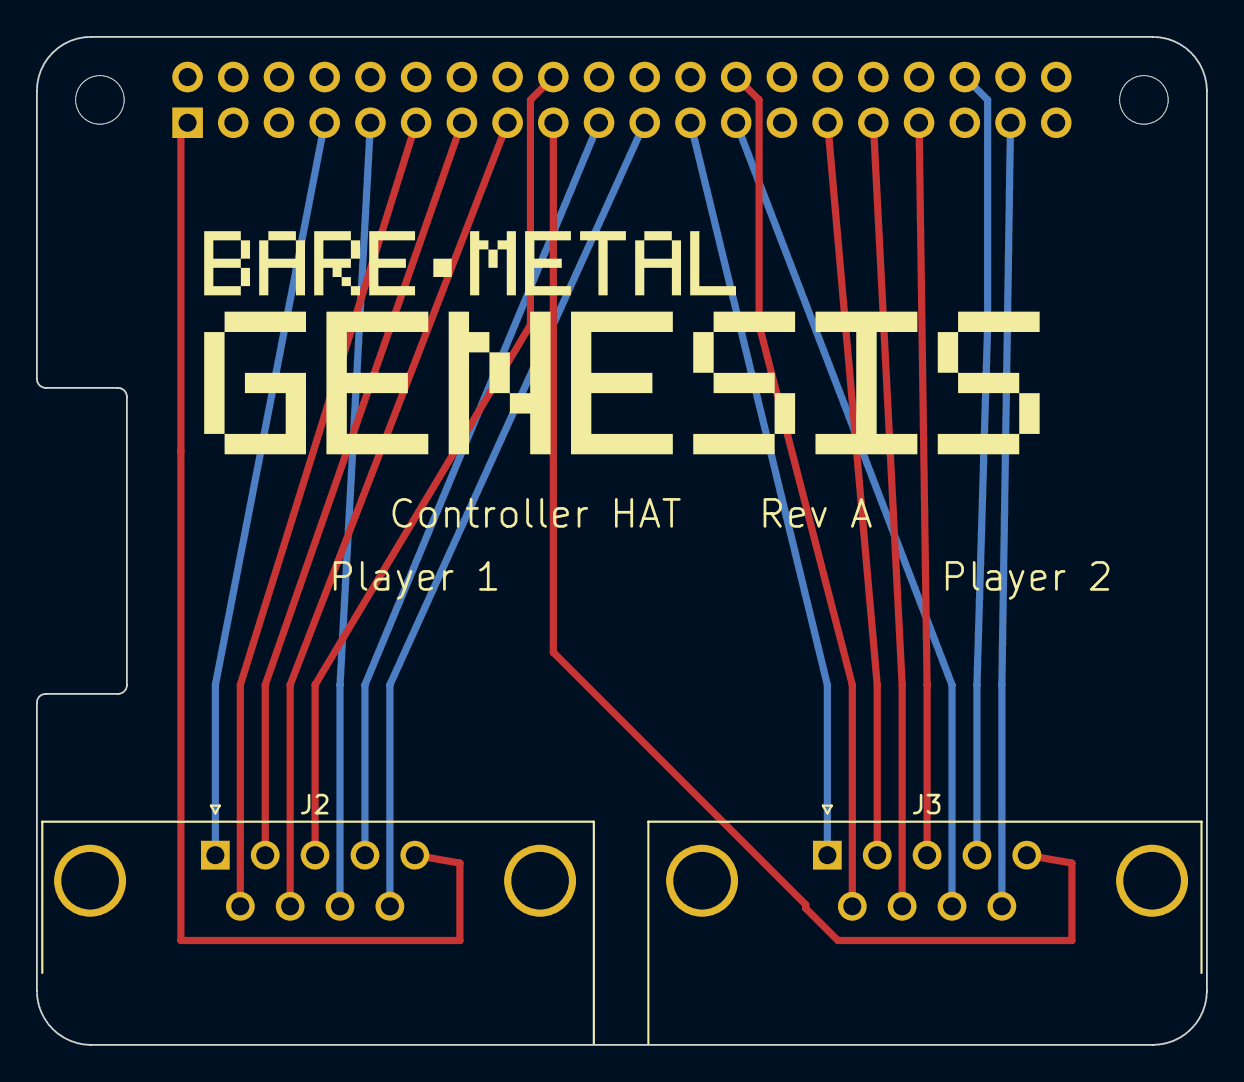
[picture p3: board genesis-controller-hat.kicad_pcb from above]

Board: 2 copper layers, 65.0 x 56.0 mm, 5 parts (1 on the bottom side), 16 nets.

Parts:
J1: PinSocket_2x20_P2.54mm_Vertical
J2, J3: DSUB-9_Pins_Horizontal_P2.77x2.84mm_EdgePinOffset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; DSUB-9_Pins_Horizontal_P2.77x2.84mm_EdgePinOffset7.70mm_Hou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
MH1, MH2: MountingHole_2.7mm_M2.5

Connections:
+3V3: J1.1, J1.17, J2.5, J3.5
/GPIO4/GPCLK0: J1.7, J2.1
/GPIO5: J1.29, J3.2
/GPIO6: J1.31, J3.7
/GPIO7/SPI0.CE1: J1.26, J3.6
/GPIO9/SPI0.MISO: J1.21, J2.9
/GPIO10/SPI0.MOSI: J1.19, J2.4
/GPIO11/SPI0.SCLK: J1.23, J3.1
/GPIO13/PWM1: J1.33, J3.3
/GPIO16: J1.36, J3.4
/GPIO17: J1.11, J2.6
/GPIO22: J1.15, J2.7
/GPIO24: J1.18, J2.3
/GPIO26: J1.37, J3.9
/GPIO27: J1.13, J2.2
GND: J1.6, J1.9, J1.14, J1.20, J1.25, J1.30, J1.34, J1.39, J2.8, J3.8

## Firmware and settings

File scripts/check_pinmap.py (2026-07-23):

#!/usr/bin/env python3
"""Verify this HAT's schematic wiring matches the firmware repo's pin map.

The firmware repo's src/input/sega_board.h is the single authoritative
source for which BCM GPIO drives each DB9 signal (see that file's own
header comment). This script extracts the *actual* wiring from the
committed KiCad schematic -- not from a markdown table or from the scripts
that built it, but from the real .kicad_sch file -- and fails if it
disagrees with sega_board.h.

Usage:
    check_pinmap.py <path/to/sega_board.h> [path/to/genesis-controller-hat.kicad_sch]

The schematic path defaults to genesis-controller-hat.kicad_sch next to
this script's repo root, so a local run only needs the header path.
"""
import argparse
import re
import sys
from pathlib import Path

REPO_ROOT = Path(__file__).resolve().parent.parent
sys.path.insert(0, str(REPO_ROOT / "scripts"))
import kicad_sexpr as ks  # noqa: E402

# DE9_Pins_MountingHoles local pin offsets (from KiCad's Connector.kicad_sym),
# relative to the symbol's own placement anchor. x is fixed per pin column;
# y varies per pin. Placing a symbol at rotation 0 puts pin N's absolute
# position at (anchor_x + local_x, anchor_y - local_y) -- KiCad negates the
# local Y offset on placement (library coordinates increase upward, page
# coordinates increase downward).
#
# DE9_Pins (male) mirrors DE9_Socket (female) in Y around pin 3 (local y=0):
# a real male DB9's pin layout is the mirror image of a female one when
# both are drawn from the same schematic vantage point. Confirmed 2026-07-22
# when J2/J3 were corrected from DE9_Socket to DE9_Pins (Genesis controllers
# have female cable ends, so the HAT needs male ports, not female sockets).
LOCAL_PIN_XY = {
    "1": (-7.62, -10.16), "6": (-7.62, -7.62), "2": (-7.62, -5.08),
    "7": (-7.62, -2.54), "3": (-7.62, 0.0), "8": (-7.62, 2.54),
    "4": (-7.62, 5.08), "9": (-7.62, 7.62), "5": (-7.62, 10.16),
}

# DB9 pin -> sega_board.h role. Pin 7 is SELECT; pins 1,2,3,4,6,9 are
# D0..D5, per sega_board.h's own comment: "Data lines D0..D5 map to DB9
# pins 1,2,3,4,6,9."
DB9_PIN_TO_ROLE = {"7": "select", "1": "D0", "2": "D1", "3": "D2", "4": "D3", "6": "D4", "9": "D5"}

CONNECTOR_TO_PORT = {"J2": "Port 1 (Player 1)", "J3": "Port 2 (Player 2)"}


def find_symbol_anchor(tree, ref):
    for n in tree:
        if isinstance(n, list) and ks.get_tag(n) == "symbol" and ks.get_property(n, "Reference") == ref:
            at = next(c for c in n if isinstance(c, list) and ks.get_tag(c) == "at")
            return float(at[1]), float(at[2])
    raise ValueError(f"symbol {ref} not found in schematic")


def label_at(tree, x, y, tol=0.01):
    for n in tree:
        if isinstance(n, list) and ks.get_tag(n) == "label":
            at = next(c for c in n if isinstance(c, list) and ks.get_tag(c) == "at")
            lx, ly = float(at[1]), float(at[2])
            if abs(lx - x) < tol and abs(ly - y) < tol:
                return n[1]
    return None


def gpio_number(label_text):
    m = re.match(r"GPIO(\d+)", label_text)
    if not m:
        raise ValueError(f"label {label_text!r} doesn't start with GPIO<n> -- unexpected net name")
    return int(m.group(1))


def extract_connector_pinmap(tree, ref):
    ax, ay = find_symbol_anchor(tree, ref)
    result = {}
    for pin, (lx, ly) in LOCAL_PIN_XY.items():
        if pin not in DB9_PIN_TO_ROLE:
            continue
        abs_x, abs_y = ax + lx, ay - ly
        label = label_at(tree, abs_x, abs_y)
        if label is None:
            raise ValueError(
                f"{ref} pin {pin}: no label found at ({abs_x:.2f}, {abs_y:.2f}) -- "
                f"schematic wiring may have moved without updating this checker's "
                f"pin-offset table"
            )
        result[DB9_PIN_TO_ROLE[pin]] = gpio_number(label)
    return result


def parse_sega_board_h(path):
    text = Path(path).read_text()
    m = re.search(
        r"kBoardPinMap\s*=\s*\{\s*\{\s*"
        r"\{\s*(\d+)\s*,\s*\{\s*(\d+)\s*,\s*(\d+)\s*,\s*(\d+)\s*,\s*(\d+)\s*,\s*(\d+)\s*,\s*(\d+)\s*\}\s*\}\s*,"
        r"(?:[ \t]*//[^\n]*)?\s*"
        r"\{\s*(\d+)\s*,\s*\{\s*(\d+)\s*,\s*(\d+)\s*,\s*(\d+)\s*,\s*(\d+)\s*,\s*(\d+)\s*,\s*(\d+)\s*\}\s*\}",
        text,
    )
    if not m:
        raise ValueError(
            f"could not find the kBoardPinMap struct in {path} -- its layout "
            f"may have changed in a way this checker's regex doesn't expect"
        )
    nums = [int(g) for g in m.groups()]
    fields = ("select", "D0", "D1", "D2", "D3", "D4", "D5")
    return dict(zip(fields, nums[:7])), dict(zip(fields, nums[7:]))


def main():
    parser = argparse.ArgumentParser(description=__doc__, formatter_class=argparse.RawDescriptionHelpFormatter)
    parser.add_argument("header_path", help="path to the firmware repo's src/input/sega_board.h")
    parser.add_argument(
        "schematic_path", nargs="?",
        default=str(REPO_ROOT / "genesis-controller-hat.kicad_sch"),
        help="path to genesis-controller-hat.kicad_sch (default: repo root)",
    )
    args = parser.parse_args()

    sch_tree = ks.parse(Path(args.schematic_path).read_text())
    hat_ports = {ref: extract_connector_pinmap(sch_tree, ref) for ref in CONNECTOR_TO_PORT}
    fw_port1, fw_port2 = parse_sega_board_h(args.header_path)
    fw_ports = {"J2": fw_port1, "J3": fw_port2}

    mismatches = []
    for ref, label in CONNECTOR_TO_PORT.items():
        hat, fw = hat_ports[ref], fw_ports[ref]
        if hat != fw:
            mismatches.append((ref, label, hat, fw))

    for ref in CONNECTOR_TO_PORT:
        print(f"{ref} ({CONNECTOR_TO_PORT[ref]}):")
        print(f"  HAT schematic:  {hat_ports[ref]}")
        print(f"  sega_board.h:   {fw_ports[ref]}")

    if mismatches:
        print()
        print("MISMATCH -- the HAT's wiring disagrees with sega_board.h:")
        for ref, label, hat, fw in mismatches:
            print(f"  {ref} ({label}): HAT has {hat}, firmware has {fw}")
        print()
        print("sega_board.h is the source of truth (see its own header comment).")
        print("Update the HAT schematic to match, not the other way around.")
        return 1

    print()
    print("OK -- HAT schematic wiring matches sega_board.h exactly.")
    return 0


if __name__ == "__main__":
    sys.exit(main())

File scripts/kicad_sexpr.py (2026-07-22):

"""Round-trip-safe S-expression parser/serializer for KiCad 9 files, plus
helpers for the specific find/remove/create operations this project's
schematic-editing scripts need. Not a general KiCad API replacement — no
pcbnew module is installed in this environment, so file-format editing is
the only scripting path available."""

import uuid as _uuid

# Global symbol libraries this project ever pulls a not-yet-cached lib_id
# from. Schematic files cache a copy of every symbol definition they use in
# their own top-level lib_symbols section; KiCad 9 fails to load a file that
# references a lib_id with no matching cache entry, even when the global
# library table resolves the nickname fine. See ensure_lib_symbol_cached().
_SYMBOL_LIBRARY_PATHS = {
    "power": "/usr/share/kicad/symbols/power.kicad_sym",
    "Connector": "/usr/share/kicad/symbols/Connector.kicad_sym",
}


class Sym(str):
    """A bare (unquoted) token, as opposed to a quoted string."""
    pass


def parse(text):
    pos = 0
    n = len(text)

    def skip_ws(p):
        while p < n and text[p] in " \t\r\n":
            p += 1
        return p

    def parse_atom(p):
        if text[p] == '"':
            p += 1
            buf = []
            while text[p] != '"':
                if text[p] == '\\':
                    esc = text[p + 1]
                    # KiCad escape sequences that are NOT "drop the backslash,
                    # keep the char verbatim": \n is a two-byte escape meaning
                    # an actual line break, not the literal letter 'n'.
                    if esc == 'n':
                        buf.append('\n')
                    elif esc == '\\':
                        buf.append('\\')
                    elif esc == '"':
                        buf.append('"')
                    else:
                        # Unrecognized escape sequence: raise instead of
                        # silently dropping the backslash, so any future
                        # corruption is surfaced immediately rather than
                        # hidden.
                        raise ValueError(
                            f"unrecognized escape sequence '\\{esc}' at position {p}"
                        )
                    p += 2
                else:
                    buf.append(text[p])
                    p += 1
            return "".join(buf), p + 1
        start = p
        while p < n and text[p] not in " \t\r\n()":
            p += 1
        return Sym(text[start:p]), p

    def parse_expr(p):
        p = skip_ws(p)
        assert text[p] == '(', f"expected '(' at {p}"
        p += 1
        items = []
        while True:
            p = skip_ws(p)
            if text[p] == ')':
                return items, p + 1
            if text[p] == '(':
                sub, p = parse_expr(p)
                items.append(sub)
            else:
                atom, p = parse_atom(p)
                items.append(atom)

    tree, _ = parse_expr(skip_ws(0))
    return tree


def serialize(node, depth=0):
    if isinstance(node, Sym):
        return str(node)
    if isinstance(node, str):
        return '"' + (node.replace('\\', '\\\\')
                          .replace('"', '\\"')
                          .replace('\n', '\\n')) + '"'
    if not any(isinstance(c, list) for c in node):
        return "(" + " ".join(serialize(c, depth) for c in node) + ")"
    indent = "\t" * (depth + 1)
    out = []
    buf = []
    for c in node:
        if isinstance(c, list):
            if buf:
                out.append(" ".join(buf))
                buf = []
            out.append(serialize(c, depth + 1))
        else:
            buf.append(serialize(c, depth))
    if buf:
        out.append(" ".join(buf))
    body = out[0] + "".join("\n" + indent + o for o in out[1:])
    return "(" + body + "\n" + ("\t" * depth) + ")"


def dumps(tree):
    return serialize(tree)


def get_tag(node):
    return node[0] if isinstance(node, list) and node else None


def get_property(symbol_node, name):
    for child in symbol_node:
        if isinstance(child, list) and get_tag(child) == "property" and child[1] == name:
            return child[2]
    return None


def find_symbols_by_ref(tree, refs):
    return [n for n in tree if isinstance(n, list) and get_tag(n) == "symbol"
            and get_property(n, "Reference") in refs]


def remove_symbols_by_ref(tree, refs):
    before = len(tree)
    tree[:] = [n for n in tree if not (isinstance(n, list) and get_tag(n) == "symbol"
                                        and get_property(n, "Reference") in refs)]
    return before - len(tree)


def remove_labels_by_text(tree, texts):
    before = len(tree)
    tree[:] = [n for n in tree if not (isinstance(n, list) and get_tag(n) == "label"
                                        and n[1] in texts)]
    return before - len(tree)


def root_uuid(tree):
    for node in tree:
        if isinstance(node, list) and get_tag(node) == "uuid":
            return node[1]
    raise ValueError("no top-level uuid found")


def project_name(tree):
    for node in tree:
        if isinstance(node, list) and get_tag(node) == "symbol":
            for child in node:
                if isinstance(child, list) and get_tag(child) == "instances":
                    for proj in child[1:]:
                        return proj[1]
    raise ValueError("no instances/project block found to infer project name")


def ensure_lib_symbol_cached(tree, lib_id):
    """Make sure tree's top-level lib_symbols section has a cached copy of
    lib_id's definition. KiCad 9 fails to load a schematic that references a
    lib_id with no matching cache entry, even when the global sym-lib-table
    resolves the library nickname correctly -- discovered while wiring up
    the first PWR_FLAG symbol this project ever added (the template's own
    lib_symbols only caches the symbols it itself uses). No-op if lib_id is
    already cached.
    """
    nickname, symbol_name = lib_id.split(":", 1)
    lib_symbols = next(n for n in tree if get_tag(n) == "lib_symbols")
    if any(isinstance(s, list) and s[1] == lib_id for s in lib_symbols[1:]):
        return
    lib_path = _SYMBOL_LIBRARY_PATHS[nickname]
    lib_tree = parse(open(lib_path).read())
    definition = next(n for n in lib_tree
                       if isinstance(n, list) and get_tag(n) == "symbol" and n[1] == symbol_name)
    # Cached entries are keyed by the full "nickname:SymbolName" lib_id, not
    # the library's own bare symbol name -- e.g. the template's cache holds
    # "power:+3.3V", not "+3.3V". Referencing a lib_id with no cache entry
    # under this exact name crashes kicad-cli's loader (confirmed: it is NOT
    # graceful, unlike a lib_id with no entry at all, which fails to load
    # cleanly instead).
    definition[1] = lib_id
    lib_symbols.append(definition)
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

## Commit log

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2026-07-22 Fix stale Global Constraint wording re: PCB editing approach
    Caught during subagent-driven-development's pre-flight plan review: the
    constraint still said all edits go through kicad_sexpr.py, but Task 6
    (written after pcbnew was confirmed working) correctly uses the pcbnew
    API for the PCB instead. Wording now matches what the tasks actually do.
2026-07-22 Scaffold KiCad project from official RaspberryPi-HAT template
    Starting from KiCad's own mechanically-correct HAT template (65x56.5mm
    outline, mounting holes, GPIO header position) instead of re-deriving the
    board outline by hand eliminates an entire class of dimensional mistakes.
    [genesis-controller-hat.kicad_pcb, genesis-controller-hat.kicad_sch]
2026-07-22 Fix backslash-escape round-trip bug in kicad_sexpr parser
    parse_atom() copied backslash-escape pairs (e.g. \") verbatim into the
    parsed string instead of unescaping them, while serialize() always
    re-escapes backslashes and quotes on the way out. This mismatch meant
    any escaped-quote content (e.g. the power-symbol Description property
    `Power symbol creates a global label with name \"+3.3V\"`) gained an
    extra layer of backslashes every time the file was parsed and dumped,
    compounding across the repeated parse-modify-dump cycles used in
    Tasks 2-5.
    Fix parse_atom to consume the backslash and following character but
    only append the following character, so the in-memory string holds
    the logical/u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
    [kicad_sexpr.py]
2026-07-22 Fix kicad_sexpr parser to handle KiCad's \n line-break escape
    The previous fix (0110ee8) changed the blanket escape rule to "drop
    backslash, keep next char verbatim", which correctly fixed \\ -> \
    and \" -> " but was wrong for KiCad's \n escape: that sequence means
    an actual line break, not the literal letter 'n'. With the prior fix,
    parsing and re-dumping the real schematic silently mashed annotation
    text together (e.g. "Additional pin functions:\nhttps://pinout.xyz/"
    became "...functions:nhttps://pinout.xyz/"), corrupting two (text ...)
    notes across 14 occurrences without changing the ERC error/warning
    count.
    parse_atom now uses an explicit escape table: \\ -> \, \" -> ", and
    \n -> an act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
    [kicad_sexpr.py]
2026-07-22 Fix token quoting and add lib_symbols caching to kicad_sexpr
    make_power_symbol/make_db9_symbol/make_label/make_no_connect built
    numeric and keyword tokens as plain Python strings, which the serializer
    then quoted -- e.g. (at "55.88" "30.0" "0") instead of KiCad's expected
    bare (at 55.88 30.0 0). Separately, referencing a lib_id with no cached
    copy in the schematic's own lib_symbols section crashes kicad-cli outright
    rather than failing gracefully, and the cached copy must be keyed by the
    full "nickname:SymbolName" form to be found at all. Both were unexercised
    until Task 2 became the first caller of make_power_symbol.
    [kicad_sexpr.py]
2026-07-22 Strip ID EEPROM circuit and +5V from the HAT schematic
    This board is not chasing official HAT certification (bare-metal kernel,
    no device-tree consumer for the EEPROM) and never uses 5V (Genesis pads
    are powered at 3.3V per the approved design spec), so both are removed
    rather than left as dead weight, along with the ID_SDA/ID_SCL label pairs
    and wiring that only existed to serve the EEPROM circuit. PWR_FLAG symbols
    replace the ERC correctness those deleted parts incidentally provided for
    the +3.3V/GND nets; GPIO0/1 get explicit no-connect flags.
    [genesis-controller-hat.kicad_sch]
2026-07-22 Correct plan Task 2 after mid-execution bug discovery
    Task 2's first implementer attempt hit a real BLOCKED failure (kicad-cli
    segfault). Root-caused directly: the plan's claim that GPIO0/1 wire
    "directly" to the EEPROM circuit was wrong (they connect via ID_SDA/ID_SCL
    local-label pairs), and scripts/kicad_sexpr.py's make_power_symbol and
    friends had never been exercised until this task, surfacing a token-
    quoting bug and a missing lib_symbols-caching step. Both are fixed and
    validated (26 errors/0 warnings reproduced exactly); Task 2's script and
    Task 4/5's ensure_lib_symbol_cached calls are corrected to match.
2026-07-22 Fix kicad_sexpr serializer to preserve KiCad's multi-line pretty-print format
    serialize() collapsed the whole tree to a single line, which turned the
    committed schematic into an unreviewable single-line blob (4000+ line
    diffs for any future change). Now a list with only atom children stays
    on one line, while a list containing any list child prints multi-line
    with tab indentation matching KiCad's own convention. Re-generated
    genesis-controller-hat.kicad_sch with the fixed serializer; ERC is
    unchanged (26 errors / 0 warnings) and parse->dump->parse->dump is
    byte-identical.
    [genesis-controller-hat.kicad_sch]
2026-07-22 Correct plan Task 3 after mid-execution bug discovery
    Same root cause as Task 2's correction: every GPIO label in the template
    sits on its own wire stub running to J1's actual pin rather than directly
    on the pin, so deleting only the label text left 12 dangling wires (26
    errors/12 warnings instead of the expected 14/0). Corrected script also
    deletes each label's connecting wire and no-connects the now-bare pin.
2026-07-22 Remove header labels for GPIO pins this HAT does not use
    I2C, UART, I2S, and the four spare GPIOs are reserved by the firmware
    repo's electrical contract but not populated on this board; deleting
    their labels, connecting wire stubs, and marking the now-bare J1 pins
    no-connect turns permanent ERC noise into a clean signal for the pins
    that remain.
    [genesis-controller-hat.kicad_sch]
2026-07-22 Correct Task 4/5 pin coordinates: KiCad negates local Y on placement
    Found and fixed before any subagent touched these tasks: the plan assumed
    absolute pin position = anchor + local_offset on both axes, but KiCad
    negates a symbol's local Y offset when placing it (library coordinates
    increase upward, page coordinates increase downward). The original J2/J3
    anchors also weren't on the 1.27mm connection grid. Both fixed and
    validated directly -- placing J2+J3 with the corrected transform and a
    grid-aligned anchor produces exactly 0 errors/0 warnings.
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2026-07-22 Wire Player 2 DB9 connector (J3) to the GPIO header
    Mirrors Task 4's Player 1 wiring onto GPIO12/13/16/17/22/11/23 per
    sega_board.h. Schematic ERC is now fully clean (0 errors, 0 warnings).
    [genesis-controller-hat.kicad_sch]
2026-07-22 Rewrite Task 6 with validated placement, routing, and honest DRC target
    Found via direct rendering/DRC iteration before dispatching: J1's real
    physical layout runs along the board's top edge (not left edge as the
    schematic symbol's orientation suggested), and the DSUB-9 footprint's
    real pad layout (2-row cluster, ~42mm courtyard) differs substantially
    from the schematic symbol's single-column layout used for wiring in
    Tasks 4-5. Corrected placement (bottom edge, opposite J1) and a validated
    greedy two-layer routing script replace the original guesses. DRC target
    is now an honest 32 errors/5 warnings (10 pre-existing, 27 disclosed as
    a known manual-routing-cleanup follow-up) rather than an un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
2026-07-22 Place, wire, and route J2/J3 DB9 connectors on the PCB
    Both DB9 sockets sit on the board's bottom edge (opposite J1, which runs
    along the top), side by side, clearing the mounting holes and camera
    slot. Built with the pcbnew Python API so net assignment goes through
    KiCad's own net table by name. Routing uses a greedy two-layer assignment
    with a per-net breakout waypoint, validated to cut DRC violations from
    151 (naive single-layer straight-line routing) to 32 errors/5 warnings --
    10 of those are pre-existing from Task 1's template, and the remaining
    27 (mostly same-layer track crossings from this specific dense pinout)
    are a disclosed, known follow-up requiring manual GUI routing cleanup
    be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
    [genesis-controller-hat.kicad_pcb]
2026-07-22 Commit Task 6 loose ends: silkscreen script, project-file fixes, gitignore
    scripts/task6_silkscreen_labels.py (Step 3 of Task 6, not explicitly
    named as a file to create in the plan's Files list but a real deliverable
    script, same pattern as every other task). genesis-controller-hat.kicad_pro
    picked up two harmless changes from running kicad-cli: a default DRC rule
    severity key, and a fix to a stale meta.filename field left over from
    Task 1's template copy (still said "RaspberryPi-HAT.kicad_pro"). Also
    ignore *.kicad_prl (machine-local project cache) and __pycache__/.
2026-07-22 Update Task 7's README text with Task 6's actual delivered DRC numbers
    Task 6 delivered 32 errors/6 warnings (not the originally-estimated 5
    warnings) plus a minor "Player 2" silkscreen label edge-clearance note
    from Task 6's review. Task 7's README section and final verification
    step now describe the real, reviewed result instead of a stale estimate.
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2026-07-22 Address final-review Minor findings: board rev silk, template cruft, parser hardening
    Adds the board name/rev silkscreen the design spec called for but Task 6
    missed; removes 7 leftover Dwgs.User annotations inherited from KiCad's
    official RaspberryPi-HAT template (PoE/RJ45/USB/camera/display notes,
    irrelevant to this DB9-only board); makes kicad_sexpr.py's parse_atom
    raise on an unrecognized backslash-escape instead of silently dropping it
    (inert today, but surfaces future corruption instead of hiding it);
    reconciles two stale DRC-count references in the plan's Task 6 narrative
    text to match the actually-delivered 32 errors/6 warnings.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
    [genesis-controller-hat.kicad_pcb]
2026-07-22 Add GND ground pour on B.Cu; add kicad-happy design review
    Adds a solid GND copper pour on B.Cu (fewer signal traces there than
    F.Cu, and J1 already sits on that layer), using direct pad connections
    rather than thermal-relief spokes -- simpler and more robust for a small
    2-layer hobbyist board, and it avoids a min-spoke-count DRC rule these
    particular THT pads couldn't satisfy with default thermal relief.
    Removes a leftover unfilled "PoE" keepout zone inherited from KiCad's
    official RaspberryPi-HAT template. Verified: unconnected_items dropped
    9->2 (the pour ties together most of J1's previously-disconnected GND
    pins), ERC unaffected (still 0/0), visually confirmed via render.
    Also adds doc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
    [genesis-controller-hat.kicad_pcb]
2026-07-22 Add CI check verifying HAT schematic wiring matches sega_board.h
    Rather than merging this repo with the firmware repo for consistency,
    adds a targeted GitHub Actions check instead: scripts/check_pinmap.py
    extracts the actual DB9-to-GPIO wiring from the committed KiCad schematic
    (not from a markdown table or the build scripts, but the real .kicad_sch
    file) and compares it against the firmware repo's src/input/sega_board.h,
    which is the documented single source of truth for this pin map. The
    workflow fetches sega_board.h from the firmware repo's public GitHub
    remote via a sparse checkout and fails the build if the two disagree.
    Verified: passes against the current schematic/header, and correc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
    [check_pinmap.py]
2026-07-22 Reassign GPIO pin map to eliminate PCB routing crossings
    Rewires J2/J3 to the new pin assignment (Port 1 select=22 data=10,23,27,17,24,4;
    Port 2 select=12 data=26,13,6,5,16,7) that groups each port's signals onto
    physically adjacent GPIO header columns nearest that port's connector. This
    lets the board route with zero same-layer trace crossings and zero
    hole-clearance violations (was 14 tracks_crossing + 4 hole_clearance),
    reducing total DRC violations from 30 errors/6 warnings to 16/6. ERC remains
    0/0, and the schematic wiring matches the firmware repo's updated
    sega_board.h exactly (verified via scripts/check_pinmap.py).
    See docs/reviews/2026-07-22-pinmap-reassignment.md for the full root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
    [genesis-controller-hat.kicad_pcb, genesis-controller-hat.kicad_sch]
2026-07-22 Remove camera flex slot cutout, freeing J3's mounting plate
    The official RaspberryPi-HAT template includes a camera flex slot (a
    narrow enclosed cutout) and a display flex cutout (a notch on the left
    edge) — both only "recommended" by the HAT mechanical spec, not required,
    and this board already isn't officially HAT-certified. The camera slot sat
    immediately next to J3, crowding what would otherwise be solid mounting
    plate around that connector; this board has no camera use case, so it's
    removed. The display cutout is left in place.
    DRC drops from 16/6 to 15/6 (one fewer copper_edge_clearance violation, one
    less board edge for the ground pour to clear). ERC unaffected (0/0).
    Co-Authored-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
    [genesis-controller-hat.kicad_pcb]
2026-07-22 Move J2/J3 inward so all 4 DSUB mounting holes sit fully on the board
    J2's left mounting hole and J3's right mounting hole previously fell
    partially/fully off the board edge (J2's left hole was bisected by the
    edge; J3's right hole was entirely off-board). Moved J2 +3mm and J3 -6mm
    so all 4 holes now sit fully on the board with ~1mm clearance to the edge,
    leaving ~2mm clearance between the two connector shells. Re-routed both
    connectors' traces to match (same breakout-and-diagonal technique as the
    pin reassignment), still achieving 0 tracks_crossing / 0 hole_clearance /
    0 copper_edge_clearance. Shifted the "Player 1"/"Player 2" silkscreen
    labels to stay centered under their connectors.
    DRC: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
    [genesis-controller-hat.kicad_pcb]
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2026-07-22 Upgrade project files to KiCad 10 format
    Ran kicad-cli sch upgrade / pcb upgrade after the toolchain was updated to
    KiCad 10.0.4 (schematic version 20250114 -> 20260306, board version
    20241229 -> 20260206, generator_version 9.0 -> 10.0).
    Also initialized this machine's KiCad 10 global sym-lib-table/fp-lib-table
    from KiCad's own default templates (~/.config/kicad/10.0/), since they'd
    never been generated (only kicad-cli had been used, never the GUI's
    first-run wizard) -- without them ERC/DRC couldn't resolve any standard
    library symbol/footprint and falsely reported ~15 ERC warnings and inflated
    lib_footprint_issues. Not a project file change, but required for this
    environment to verify the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
    [genesis-controller-hat.kicad_pcb, genesis-controller-hat.kicad_sch]
2026-07-22 Add Bare-Metal Genesis wordmark logo to board silkscreen
    Replaces the plain "Genesis Controller HAT" title text with the wordmark
    logo from design_files/Bare-metal Sega Genesis-handoff.zip
    (project/kicad/bmg-logo-wordmark.svg). The source SVG is entirely
    axis-aligned rects (pixel-art style), so it converts directly to 153
    filled gr_rect silkscreen shapes on F.Silkscreen at 1:1 fidelity, no
    tracing/vectorization needed. Sized 48mm wide (~14mm tall) and centered in
    the open area between J1 and the DB9 connectors; "Rev A" nudged down
    slightly to stay clear of it.
    ERC/DRC unaffected (silkscreen doesn't need clearance from the copper
    traces it visually sits over). Added design_files/ to the repo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
    [genesis-controller-hat.kicad_pcb]
2026-07-22 Add back "Controller HAT" text, in line with "Rev A"
    Restores the "Controller HAT" part of the old title text (dropped when the
    wordmark logo replaced "Genesis Controller HAT"), placed on the same line
    as "Rev A" just below the logo. Both centered as a pair under the logo,
    clear of the logo above and the Player 1/Player 2 labels below.
    ERC/DRC unaffected (0 errors/2 warnings, 17/5 -- same as before).
    [genesis-controller-hat.kicad_pcb]
2026-07-22 Add repo URL and build date to back silkscreen
    Front silkscreen was already full (logo, title, port labels), so the repo
    URL (github.com/mjaydedecker/Bare-Metal-Sega-Genesis-Hat) and a "Jul 2026"
    build date go on B.Silkscreen instead. Set SetMirrored(True) on both --
    without it, back-layer text renders backwards once the board is physically
    flipped over (confirmed by rendering --side bottom before and after).
    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
    [genesis-controller-hat.kicad_pcb]
2026-07-22 Fix shorting_items and solder_mask_bridge by jogging tracks around J1's row-A pins
    Root cause: J1's two pin rows are only 2.54mm apart. A track targeting a
    row-B pin was routed as a straight diagonal that skimmed directly past the
    row-A pin in the same column, since the diagonal has to pass through that
    column's row-A position en route to row-B. Fixed by rerouting each affected
    track (/GPIO24, /GPIO23, /GPIO7/SPI0.CE1, GND, /GPIO16, /GPIO12/PWM0) as:
    breakout -> horizontal repositioning done entirely above J1's pin field
    (y=60, clear of any pad) -> a pure-vertical run at a waypoint X exactly
    between two header columns -> a short final hop into the target pad. Layer
    assignment for all 12 sign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
    [genesis-controller-hat.kicad_pcb]
2026-07-22 Resolve GPIO12/PWM0-vs-GND crossing; incorporate manual GPIO6 reroute
    Builds on a manual reroute of /GPIO6 further left (clearing space around
    x=147.74), which opened room for /GPIO12/PWM0 to approach its target (J1
    pin 32) from the opposite side of the pin, on F.Cu -- parallel to /GPIO6
    instead of crossing GND on B.Cu. This was tried once before this session
    without the /GPIO6 reroute and made things worse (new shorting_items
    against /GPIO6, since the two ran too close together); with /GPIO6 moved
    out of the way first, it now resolves cleanly with no new violations.
    tracks_crossing: 2 -> 1 (only /GPIO24 vs /GPIO10/SPI0.MOSI/+3V3 remains,
    a separate three-way layer conflict). Total DRC: 6 e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
    [genesis-controller-hat.kicad_pcb]
2026-07-22 Resolve final tracks_crossing violation -- routing now fully clean
    Rerouted /GPIO10/SPI0.MOSI to F.Cu with its own jog around J1's row-A pins
    (same technique as the other affected nets), clearing both +3V3 and
    /GPIO24 without disturbing either. That was the last of the three-way
    layer conflict in this cluster.
    tracks_crossing, shorting_items, solder_mask_bridge, hole_clearance, and
    copper_edge_clearance are all now zero. Total DRC: 5 errors/5 warnings ->
    4/5 -- only pre-existing/cosmetic items remain (courtyards_overlap,
    unconnected_items, lib_footprint_mismatch, silk_edge_clearance). ERC and
    check_pinmap.py unaffected.
    [genesis-controller-hat.kicad_pcb]
2026-07-22 Remove MH3/MH4 corner mounting holes -- physically unusable
    J2 and J3's edge-mount brackets already overlapped these two holes
    (courtyards_overlap), meaning their mounting screws could never actually
    be installed -- the DSUB plastic occupies the space. Rather than leave
    dead-weight holes in the design, removed both. courtyards_overlap is now
    zero.
    This board now mounts on only the 2 remaining top corner holes (MH1/MH2,
    next to the GPIO header) plus the GPIO header's friction fit, and no
    longer meets the official HAT spec's 4-corner-hole requirement -- already
    not pursuing certification (see design spec's "Scope decisions"). Also
    corrects an earlier README claim that this was a "3-point moun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
    [genesis-controller-hat.kicad_pcb]
2026-07-22 Fix ERC lib_symbol_mismatch warnings -- ERC now fully clean
    J2/J3's cached DE9_Socket_MountingHoles symbol (embedded in the
    schematic's own lib_symbols section) drifted from KiCad 10's revised copy
    of that library symbol during the earlier format upgrade. Added
    refresh_lib_symbol_cache(tree, lib_id) to scripts/kicad_sexpr.py --
    replaces a stale cached symbol definition with the current one from the
    system library -- and used it to resync J2/J3's cache.
    ERC: 0 errors/2 warnings -> 0/0. DRC and check_pinmap.py unaffected
    (schematic wiring/electrical topology unchanged, only the cached visual
    symbol definition was refreshed). lib_footprint_mismatch on the PCB side
    is a different mechanism (a f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
    [genesis-controller-hat.kicad_sch]
2026-07-22 Fix silk_edge_clearance warnings -- routing/DRC nearly fully clean
    J2/J3's outline-box silkscreen had two sides running along the board edge:
    J2's left side sat 0.025mm past the edge (accounting for the line's
    0.12mm stroke width, it physically crossed the boundary), and both
    connectors' outer sides extended down into the rounded bottom corners,
    where the board narrows and the line ends up outside the board entirely.
    Nudged each offending vertical line ~0.3mm inward and trimmed its length
    to stop at y=96 (just above where the corner rounding starts at y=97);
    adjusted the matching top horizontal line's endpoint to match. Purely
    cosmetic silkscreen-artwork edits on these two footprint instanc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
    [genesis-controller-hat.kicad_pcb]
2026-07-22 Fix lib_footprint_mismatch -- DRC down to a single pre-existing item
    J1's embedded PinSocket_2x20_P2.54mm_Vertical footprint drifted from the
    system library's copy during the KiCad 9->10 upgrade (pad shape changed
    from OVAL to CIRCLE -- cosmetic for a 1.7x1.7mm round pad, since equal
    width/height makes the two shapes identical). Fixed the same way as the
    schematic-side symbol drift: removed J1, added a fresh copy of the same
    footprint straight from the system library at the same position/rotation/
    flip state, and reassigned every pad's net by pad number. Verified pad
    count, positions, sizes, and drills matched exactly before swapping (only
    shape differed).
    Side effect: unconnected_items dro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
    [genesis-controller-hat.kicad_pcb]
2026-07-23 Correct J2/J3 from female DB9 sockets to male DB9 pins
    A real Sega Genesis controller's cable ends in a female DB9 connector, so
    the HAT needs male ports to receive it -- the opposite of what had been
    designed. This was never checked against a datasheet, photo, or real
    hardware until physically verified against two real controllers (original
    and third-party). Corrected schematic symbols (DE9_Socket_MountingHoles ->
    DE9_Pins_MountingHoles) and PCB footprints (DSUB-9_Socket_Horizontal_... ->
    DSUB-9_Pins_Horizontal_..., same overhang/mounting-hole variant).
    A male DB9's physical pin order mirrors a female one's left-to-right, which
    broke the earlier GPIO reassignment's careful non-crossing cor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
    [genesis-controller-hat.kicad_pcb, genesis-controller-hat.kicad_sch]
2026-07-23 Fix stale Footprint property on J2/J3 -- ERC still 0/0
    Schematic Footprint property still pointed at the pre-rework
    DSUB-9_Socket_Vertical footprint (wrong gender, wrong orientation),
    even though the actual PCB footprint and lib_id were already correct.
    Left as-is, it would silently revert J2/J3 on the next "Update PCB
    from Schematic".
    [genesis-controller-hat.kicad_sch]
2026-07-23 Fix +3V3 same-layer track crossings, clean up J2/J3 routing -- DRC 0/0
    +3V3 crossed 8 other nets on F.Cu on its way from J1 to J2/J3 pin 5
    (a real short, not just a DRC nitpick -- kicad-cli was only surfacing
    4 of the 8). Rerouted both +3V3 legs to go around the outside of the
    J2/J3 pin field instead of weaving between individual pins, entering
    pin 5 from clear space beyond the connector rather than crossing the
    other GPIO nets' traces. Segment count for +3V3 dropped from 87 to 13.
    Verified with kicad-cli pcb drc --refill-zones: 0 violations. The one
    remaining "unconnected pad" report is benign and pre-existing -- +3V3
    is two disconnected copper islands on this board, but both get power
    fro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
    [genesis-controller-hat.kicad_pcb]
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
